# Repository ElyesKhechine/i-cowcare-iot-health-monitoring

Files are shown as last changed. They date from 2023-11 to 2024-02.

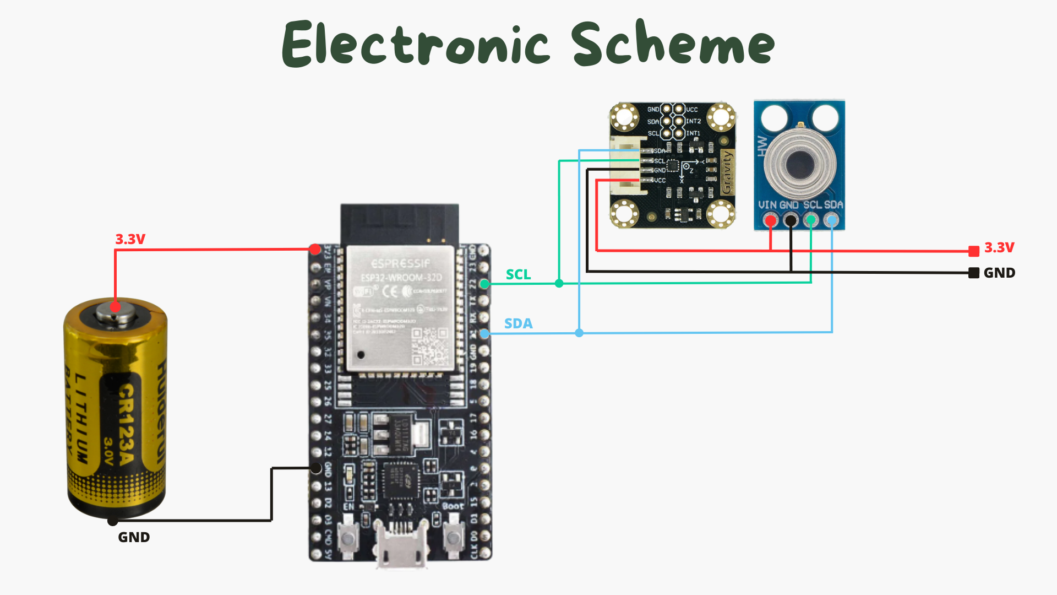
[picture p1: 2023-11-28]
Work_Progression/3_Meeting_10-04-2023/10-04-2023_Electronic_Scheme_I-CowCare_PFA_2022-2023.png

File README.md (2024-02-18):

# I-Cow-Care: IoT System for AI-Based Cow Health Monitoring

### INSAT IIA4

**Technologies:** Embedded C, ESP32, UART, I2C, MQTT, Mosquitto, CSV, JSON, Node-RED, Firebase, Edge Impulse, DNN

## Introduction

This project presents an IoT solution for cow health monitoring. The IoT device (Wearable Collar for cows) will help cow breeders detect cow health problems, and cow reproduction cycle in order to increase milk productivity and help prevent sickness and diseases among cows. This also gives the user easy access to the cow's vital indicators and helps predict its needs.

We used an ESP32, MLX90614 temperature sensor, LIS2DH accelerometer, and Lithium Polymer battery for power.

The steps below presenting the work done to establish the IoT network and prepare the hardware and software environment are going to be tackled with more details later.

1/ Install MQTT: MQTT will be our data transfer protocol using Wifi. We can use local or online MQTT servers. In our case we use Mosquitto MQTT locally and HiveMQTT as an online server.

2/ Prepare the script to connect to Wifi and MQTT, read data from sensors, and send data to the database/dashboard using MQTT protocol...(includes testing sensors, importing libraries, timestamp, etc.)

3/ Prepare the database for data storage and management using Firebase.

4/ Prepare a dashboard for data visualization and analysis using Node-RED.

5/ Hardware design: 3D mechanical and electronic design.

6/ Train machine learning models using Edge Impulse Platform for Embedded ML.

## Project Scope

Commencing from March 23, 2023, to June 1, 2023, the project undertook comprehensive research and development phases to design and implement an intelligent system for continuous cow health monitoring.

## Project Presentation

For a detailed overview of the project, including methodologies, findings, and outcomes, please refer to the [Project Presentation](https://www.canva.com/design/DAF2yuFe7VU/87OEpLmWulKL93VecQ9gpw/view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).

## Project Report

For comprehensive insights into project development, methodologies, and results, please refer to the [Project Report](https://drive.google.com/file/d/1peptsb_B581SGEHA1yHLA451OdRUzvFM/view?usp=sharing).

## Technical Details

- **Sensor Selection**: Careful selection of accelerometer and temperature sensors to optimize accuracy and efficiency, enabling over 3400 hours of continuous health monitoring with a 1300mAh lithium battery.
- **Custom Embedded C Library**: Development of a resource-efficient embedded C library for ESP32, facilitating seamless Wi-Fi connectivity, sensor data acquisition, and database publishing via MQTT, resulting in a 45% reduction in power consumption and memory utilization.
- **Data Acquisition and Storage**: Implementation of a streamlined process for data acquisition, storage, and retrieval, ensuring efficient communication with Firebase, transmission at 10 Hz, and generation of structured CSV files for DNN model training.
- **Node-RED Dashboard**: Creation of a Node-RED dashboard for visualizing body temperature and acceleration data, enhancing monitoring capabilities.
- **Supervised ML Models**: Collaboration on building supervised ML models using Edge Impulse, achieving a commendable 77% accuracy rate in classifying cow behaviors.

## Getting Started

# 1/ Installation and environment preparation

### Install Mosquitto MQTT 

in our case, the implementation was on Windows 10, and the procedure is similar for Linux, and MacOS

1/ Download link: https://mosquitto.org/download/
2/ Modify the configuration file:
To ensure the proper functioning of the Mosquitto broker, you need to manually modify the listener configuration for port 1883 in the configuration file in Mosquitto root folder.
3/ Start the MQTT server by running this command in the mosquitto root folder :
  
```bash
mosquitto -c mosquitto. conf -v
```
4/ To get the IP address, run this command (IPV4 in our case) :
```bash
ip config
```
5/ Configure the ESP32 code to connect to the MQTT server.

### Install Node-RED

1/ Download link: https://nodered.org/docs/getting-started/. You need to install node.js.

2/ Run Node-RED using this command :
  
```bash
node-red
```
3/ A local webpage will open in your browser to create, modify and connect your devices and different functions. You can connect to the database / MQTT server...

### Write script for ESP32 :

1/ We used Arduino IDE to program the ESP32  You'll find the whole script and library in the repository.

### Deep Learning :

1/ Data Preprocessing:  We engaged in data preprocessing, a step that involved tasks such as data cleansing, noise reduction, and handling missing values within the CSV dataset.

2/ Feature Extraction: We extracted spectral and temporal features from the preprocessed data.

3/ Neural Network Construction and Training: We designed and trained a neural network tailored to our dataset using the Edge Impulse platform. We then exported the TfLite model. 

Edge impulse link: https://edgeimpulse.com/

### 3D Design :
We used SolidWorks to design different parts of the device.

## Next Steps :
The project is far from being perfect or completed. The following steps may include enlarging and building a bigger database to ensure our sufficiency of data for model training. It may also include building a mobile application to facilitate access to data and different stats for different categories of users.

## Demo

### MQTT

MQTT1
MQTT2
MQTT3

### Firebase

Firebase realtime data

### Node-RED / Dashboard

begin cmd
dashboard nodes
dashboard1
dashboard2
dashboard3
### Edge Impulse

validation set


### Mechanical Design

CollarRender5
CollarRender4
CollarRender3
CollarRender2
CollarRender1
CollarNeck4
CollarNeck3

### Electronic Scheme

SCL

### Flow Diagram

SCL (1)

## Authors

This contribution to the project wasn't possible without the participation of the outstanding team :
- Edris Hadj Khlil: edris.hadjkhlil@insat.ucar.tn
- Majd Karoui: majd.karoui@insat.ucar.tn
- Niam Oueslaiti: niam.oueslaiti@insat.ucar.tn
- Elyes Khechine: elyes.khechine@insat.ucar.tn
  
And the supervision of our professors :
- Imen Harbaoui: imen.harbaoui@insat.ucar.tn
- Rabaa Youssef: rabaa.youssef@insat.ucar.tn

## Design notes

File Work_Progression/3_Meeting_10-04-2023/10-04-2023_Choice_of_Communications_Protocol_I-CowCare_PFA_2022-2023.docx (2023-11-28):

For cow heat detection devices on farms, MQTT or CoAP could be suitable protocols, as they are designed for low-bandwidth networks and can handle small data packets efficiently. Both protocols are also suitable for resource-constrained devices, which is important if the cow heat detection devices are small and battery-powered.

Additionally, the publish-subscribe model of MQTT could be beneficial for farms with multiple cow heat detection devices, as it allows for efficient communication between devices and a central server or cloud-based platform. CoAP's request-response model may also be appropriate for this type of application, as it allows for efficient exchange of information between the cow heat detection devices and the server.

The frequency of reading a temperature in the MLX90614 temperature sensor depends on how it is programmed and configured. The sensor can operate in two modes: continuous and single-shot.

In single-shot mode, the sensor provides a single temperature reading when it receives a trigger command from the device that is connected to it. The frequency of temperature readings in this mode depends on how often the trigger command is sent to the sensor.

the readout rate of the sensor can also vary depending on factors such as the communication protocol (I2C or SMBus), both of which have their own maximum transfer rates.

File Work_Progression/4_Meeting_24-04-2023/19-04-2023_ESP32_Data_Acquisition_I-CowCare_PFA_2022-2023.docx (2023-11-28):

- ESP32 Stockage : 520 KB of on-chip SRAM for data and instructions.
- 8 KB of SRAM in RTC, which is called RTC FAST Memory and can be used for data storage; it is accessed by the main CPU during RTC Boot from the Deep-sleep mode.
- 8 KB of SRAM in RTC, which is called RTC SLOW Memory and can be accessed by the co-processor during the Deep-sleep mode.

Temperature values :

1 feedback= 1 float = 4B

Accelerometer/Gyroscope values :

1 feedback = 6 floats = 24B

- code size : 206KB (memoire flash)

data storage and batch sending: aquisition frequency 4Hz

chaque 10s :

- temps de lecture : 0.4 s
- sleep mode 9.6

10s = 40 valeurs = 1KB

débit transmission de données via wifi : 19MB/s

à transmettre : 1KB

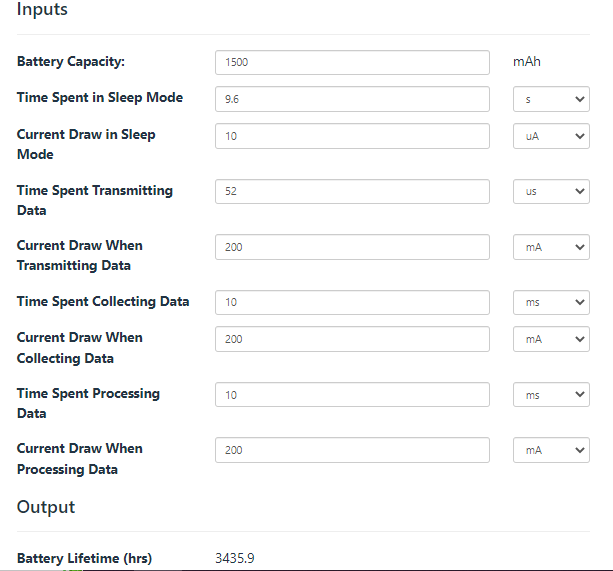
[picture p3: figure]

= 143 jours

Data cleaning au niveau du collier :

ESP32 is equipped with a dual-core processor that can run up to 240 MHz, which makes it capable of handling complex data processing tasks.

The suitability of ESP32 for data cleaning will depend on the specific requirements of the use case. Our data cleaning needs are rather simple , so the ESP32 can handle the tasks.

The data cleaning process takes time and consumes energy which reduces the collar’s battery life.

It's worth noting that the actual data cleaning process would typically occur on the server-side rather than on the collar itself, as the server typically has more processing power and storage capacity. The role of the collar would be to collect and transmit the raw data to the server for processing and analysis.

____________

Battery Life = Battery Capacity / [(Current Consumption of Controller + Current Consumption of Temperature Sensor + Current Consumption of Accelerometer) x Duty Cycle + Self-Discharge Current]

Duty Cycle = The percentage of time the device spends in active mode during a given period

Self-Discharge Current = The amount of current consumed by the battery during sleep mode. It can be estimated by considering the specifications of the battery and the quiescent current of the ESP32 board during sleep mode.

Example

To calculate the consumption of the controller, we can use the following formula:

Controller Consumption = 300 mA (during active mode) x Duty Cycle + Quiescent Current (during sleep mode)

Assuming a quiescent current of 20 uA during sleep mode, and a duty cycle of 1.11%, the controller consumption can be calculated as follows:

Controller Consumption = 300 mA x 1.11% + 20 uA

Controller Consumption = 3.33 mA + 20 uA

Controller Consumption = 3.35 mA

To calculate the current consumption of the temperature sensor, we can use the formula:

Temperature Sensor Consumption = 1 mA x Duty Cycle

Assuming a duty cycle of 1.11%, the current consumption of the temperature sensor can be calculated as follows:

Temperature Sensor Consumption = 1 mA x 1.11%

Temperature Sensor Consumption = 0.0111 mA

To calculate the current consumption of the accelerometer, we can use the formula:

Accelerometer Consumption = 200 uA x Duty Cycle

Assuming a duty cycle of 1.11%, the current consumption of the accelerometer can be calculated as follows:

Accelerometer Consumption = 200 uA x 1.11%

Accelerometer Consumption = 2.22 uA

The self-discharge current can be estimated based on the battery specifications and the quiescent current of the controller during sleep mode. Assuming a quiescent current of 20 uA during sleep mode, and a battery capacity of 1600 mAh, the self-discharge current can be calculated as follows:

Self-Discharge Current = Battery Capacity / (365 x 24 x 3600) x Quiescent Current

Self-Discharge Current = 1600 mAh / (365 x 24 x 3600) x 20 uA

Self-Discharge Current = 0.00000000221 A or 2.21 nA

Finally, we can calculate the duty cycle using the following formula:

Duty Cycle = Active Time / (Active Time + Sleep Time)

Assuming the system is active for 10 seconds every 15 minutes, the duty cycle can be calculated as follows:

Active Time = 10 seconds

Sleep Time = 15 minutes - 10 seconds = 899 seconds

Duty Cycle = 10 / (10 + 899) x 100

Duty Cycle = 1.11%

Using the values calculated above, we can estimate the expected battery life as follows:

Battery Life = Battery Capacity / [(Controller Consumption + Temperature Sensor Consumption + Accelerometer Consumption) x Duty Cycle + Self-Discharge Current]

Battery Life = 1600 mAh / [(3.35 mA + 0.0111 mA + 2.22 uA) x 1.11% + 2.21 nA] = 109.72 days

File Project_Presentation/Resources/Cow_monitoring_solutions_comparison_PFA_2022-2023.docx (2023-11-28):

Afimilk:

Utilizing a unique 3D accelerometer, Afimilk enables efficient monitoring of motion patterns. The Afi2Go Pro mobile app provides convenient access to the system from anywhere, at any time. With its robust mechanical design, Afimilk achieves a remarkable 95% detection sensitivity in various farm conditions. By employing three sensors, Afimilk enhances detection capabilities. The electrical design of Afimilk ensures an extended battery life spanning multiple years. Afimilk boasts a range of 200-800m. Currently, Afimilk's technology manages over 10 million cows in 52 countries worldwide.

__________________

Nedap:

Nedap offers a neck and leg tag system for dairy cows. The system includes features such as heat detection, cow locating, and health monitoring. It provides herd performance trends and delivers real-time information on all devices for multiple users, including PCs, tablets, and smartphones. The data is transferred wirelessly in real-time with a sensitivity of 95% and specificity of 95%. The tags have an expected service life of 8-10 years. They also support long-range data transfer and are constructed using robust materials engineered to withstand the farm environment.

__________________

Smartbow

INDUSTRY-LEADING RUMINATION MONITORING: provides the most accurate rumination monitoring in the industry, 97% to 99% accuracy delivers two types of rumination alerts — an urgent decline in rumination and a long-term decline in rumination.

UNPARALLELED HEAT DETECTION: heats can be detected with a reliability of 97% generates alarms on smartphones, tablets and desktop computers

Price: 2.500$ for the installation +69$ per cow (only for heat detection)

__________________

Smaxtec Cowcontrol

SMAXTEC BOLUSES CONTINUOUSLY COLLECT DATA: The rumen bolus measures direct, insightful values with the highest accuracy inside your cows, in the reticulum. The bolus remains inside the cow for a lifetime. It remains in the same position due to its own weight, and is neither regurgitated nor digested.

HEAT DETECTION allowing higher inseminaiton success

24/7 MONITORING

EARLY DETECTION

optimized for PC and phone (IOS,ANDROID)

RECOMMENDED ACTIONS using AI

ensuring herd health

calving detection

Price: 89$ +2.49$ per cow per month(data interpretation)

__________________

The MooMonitor+ is a state-of-the-art system that utilizes cloud computing, wearable sensors, and big data to enhance health and reproductive monitoring for cows. It enables easy detection of heats by monitoring the entire herd through the phone application, MooMonitor+. Real-time notifications provide updates on the cows' activity and health. The pricing for the system includes €140 per collar, €4,500 for the base station, and an additional charge of €5 per cow per year for the cloud monitoring system.

_________________

Moonyst Catle Monitoring

Plug & Play installation, optimized for phone, tablet and PC

Real-time access via cloud computing with 24/7 rumen monitoring

Boluses are maintenance-free, orally administered sensors with unique IDs and 6+ years battery life

Captures animal activity, rumen temperature, and movement

Mooncloud software application provides dedicated location for livestock information accessible via phone, tablet or PC

Supports calving, facilitates insemination, and prevents diseases

Improves success rates with insemination and provides real-time alerts of calving events (days/hours in advance)

Enables timely and targeted medication treatments with advanced warning of health concerns

Precise monitoring of drinking behavior for feeds into animal health monitoring

Artificial intelligence used for individual animal heats identification and prediction

Enhances expert herdsmanship with technology

Tailored status periods within Mooncloud for each cow's specific status.

size: 100 mm × 32 mm // weight: cca. 200g

__________________

e-Stado:

Sensors:

-Ear biosensors

-Environment sensor

-Tail biosensor

-Radio transmitters in the cowshed and pasture

-Cowshed monitor

Features:

Health:

-Measurement of inactivity to identify potential threats

-Measurement of ear temperature to detect health issues

Reproduction:

-Detection of heat for optimal timing of insemination

-Estimation of the optimal insemination window

Calving:

-Estimation of the incoming calving time

-Postpartum retention monitoring

Feeding:

-Monitoring of rumination time

-Monitoring of feed intake time

Photoperiod:

-Measurement of individual photoperiod cycles

Heat stress:

-Detection of individual heat stress

-Measurement of barn humidity

-Measurement of barn temperature

-Calculation of barn THI (Temperature-Humidity Index) Lameness:

-Early detection of lameness stages.

__________________

CowManager

Real-time monitoring of cow behavior and health using wireless router located in the farm

Wireless ear tags with long-lasting batteries

Cloud-based software with a user-friendly interface

Customizable alerts

Integration with other farm management systems

Sustainability-focused approach.

Real time Monitoring

Detects fertility, illness, activity, eating behaviour

__________________

Ayushman Cowfit

Uses IoT technology to monitor cattle health

Early detection of health issues

Collar with sensors on the cow's neck

Cloud-based analysis with real-time insights and alerts

User-friendly mobile app and web portal

Actionable recommendations for improving cattle health

Cost-effective and scalable

Reduces need for frequent check-ups and saves time and money.

Price: €90 per collar

__________________

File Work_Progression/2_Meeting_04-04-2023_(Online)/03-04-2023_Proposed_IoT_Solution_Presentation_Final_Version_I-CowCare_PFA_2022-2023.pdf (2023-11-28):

# ICowCare

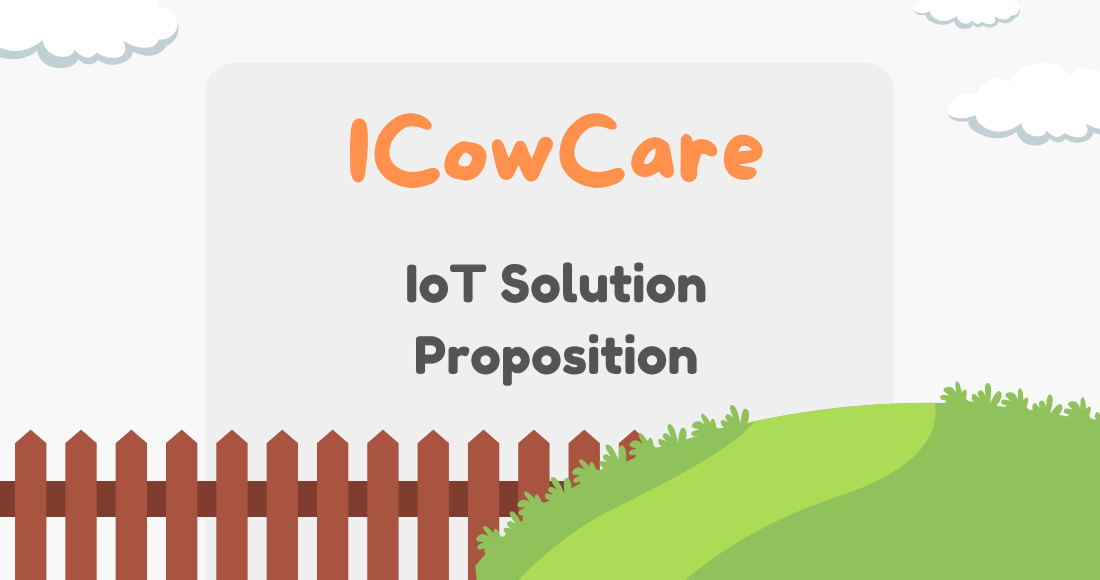
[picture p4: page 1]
IoT Solution Proposition

# Development board

## ESP32-DevKitC V4

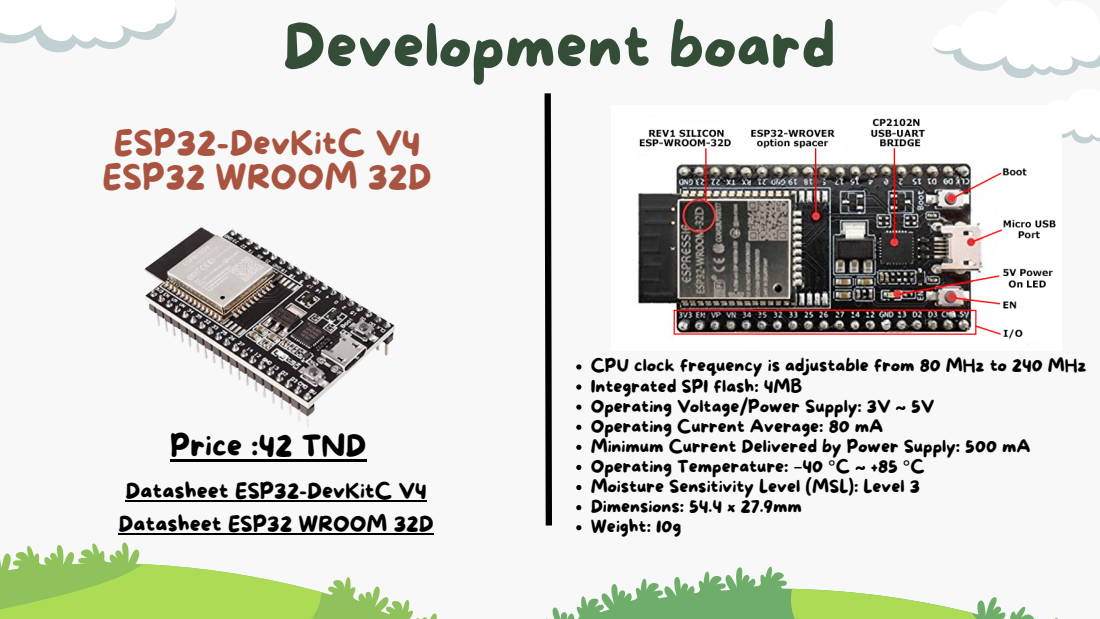
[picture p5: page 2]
ESP32 WROOM 32D; Price :42 TND; Datasheet ESP32-DevKitC V4 Datasheet ESP32 WROOM 32D

CPU clock frequency is adjustable from 80 MHz to 240 MHz
Integrated SPI flash: 4MB
Operating Voltage/Power Supply: 3V ~ 5V
Operating Current Average: 80 mA
Minimum Current Delivered by Power Supply: 500 mA
Operating Temperature: –40 °C ~ +85 °C
Moisture Sensitivity Level (MSL): Level 3
Dimensions: 54.4 x 27.9mm
Weight: 10g

# Power Supply

## Lithium battery CR123/CR123A

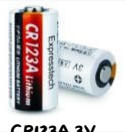
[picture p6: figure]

CR123A 3V
1300MAH
Price :9.5TND
Seli.tn (https://seli.tn/page1?recherche=cr123)

These keep a voltage of 3V quite constant, at less than 2.7 volts more than 90% of the capacity of a lithium battery is used, at 2.55 volts it is practically empty. Lithium batteries also provide the high short-term power requirements of WiFi operation without any problems. For example, a Varta CR123 (3V, 1700 mAh) can even be used in standby mode for over 5 years, depending, of course, on how often the ESP32 wakes up and has to do something, or how long and how often WiFi or Bluetooth is used.
As lithium batteries have a very low self-discharge and also function well at -20 °C,

ANSMANN 3V
1500MAH
Price :15.5TND
brico-direct.tn (https://brico-direct.tn/piles-batteries/2366-pile-speciale-cr123a-ansmann-4013674020010.html)

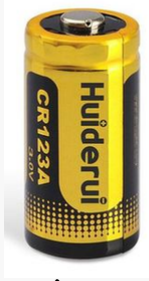
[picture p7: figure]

Huiderui 3V
1600MAH
Price :17TND
jumia.tn (https://www.jumia.com.tn/huiderui-pile-3v-batterie-au-lithium-primaire-cr123a-688849.html)

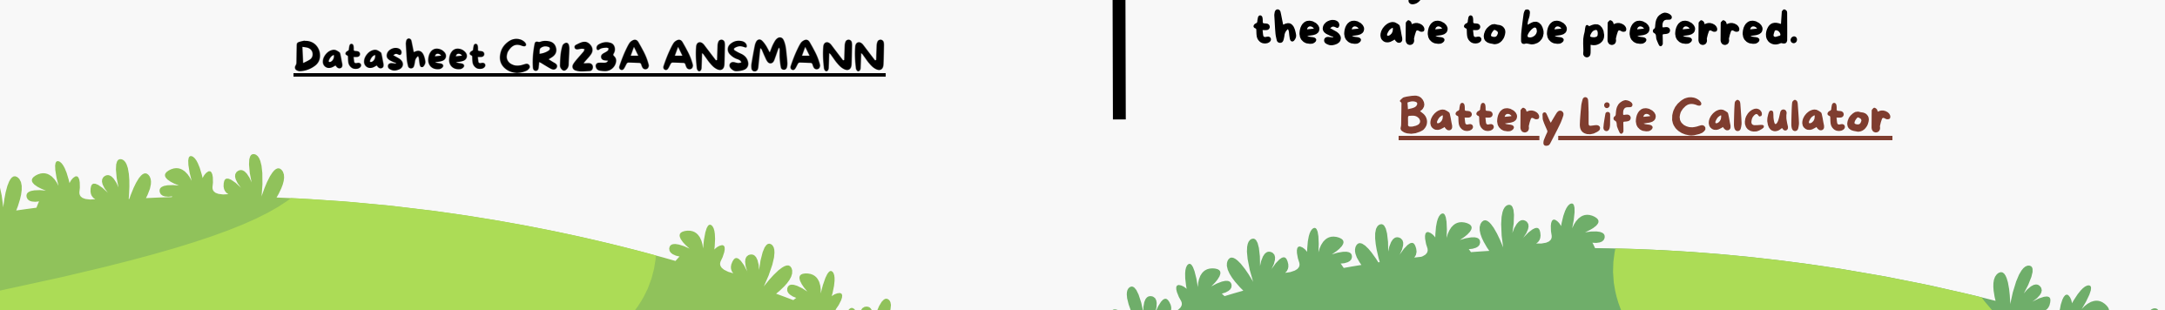
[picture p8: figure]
Datasheet CR123A ANSMANN; these are to be preferred.; Battery Life Calculator

# Server

### SERVEUR RACK DELL

POWEREDGE R230 (https://www.tunisianet.com.tn/serveur-informatique-tunisie/49088-serveur-rack-dell-poweredge-r230-2-to-8-go.html)

Reliability: The Dell PowerEdge R230 is a reliable server that is built to withstand long hours of operation.
Performance: The server is powered by an Intel Xeon E3-1220 v6 processor, which offers good performance for tasks such as cow monitoring.
Storage: The server comes with 2TB of storage, which should be enough
RAM: The server has 8GB of RAM, which is adequate for running the applications required.
Connectivity: The server has built-in Ethernet connectivity, which makes it easy to connect to the network and access the

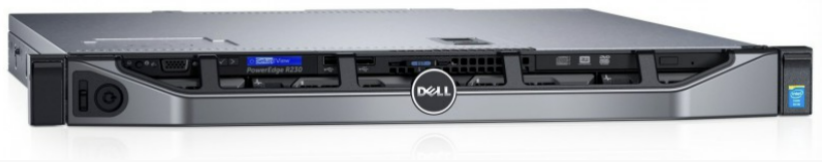
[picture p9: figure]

Price: 2.739

mytek (https://www.mytek.tn/serveur-dell-poweredge-r230-e3-1220v6-8go-1to-1u-per230a1.html) 2.549

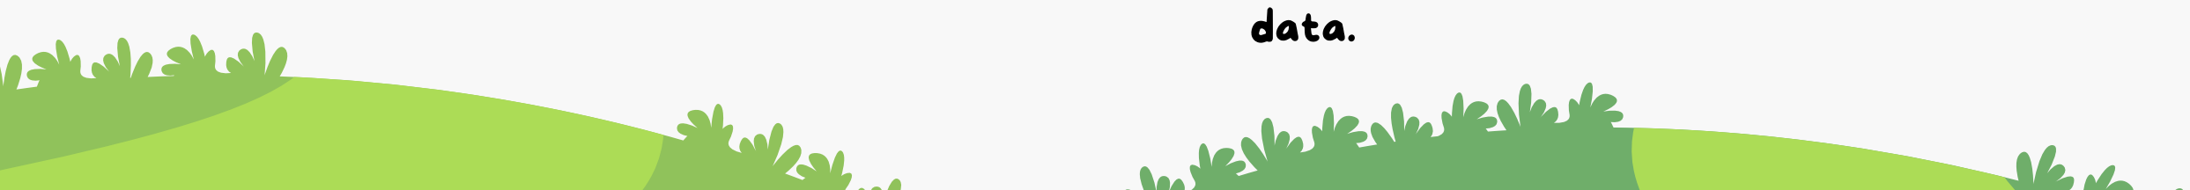
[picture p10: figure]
data.

# Cloud option

Requires good internet connection can incur ongoing costs, such as data transfer and storage fees.

AWS (https://aws.amazon.com/pricing/)
Azure (https://azure.microsoft.com/en-us/pricing/)
Google Cloud Platform (https://cloud.google.com/pricing)

Here are the links to the pricing pages for each
AWS | provider:

: starts at around $10 per month for a basic t2.micro instance with 1 vCPU and 1GB
RAM.
Azure: starts at around $15 per month for a basic B1s instance with 1 vCPU and 1GB RAM.
Google Cloud Platform: starts at around $10 per month for a basic f1-micro instance with 1 vCPU and 0.6GB RAM.

the pricing for AWS, Azure, and Google Cloud Platform can vary widely depending on factors such as the specific services used, the location, and the duration of usage. However, here are some rough estimates for the cost of running a basic virtual machine in each cloud provider:

# Arduino Cloud

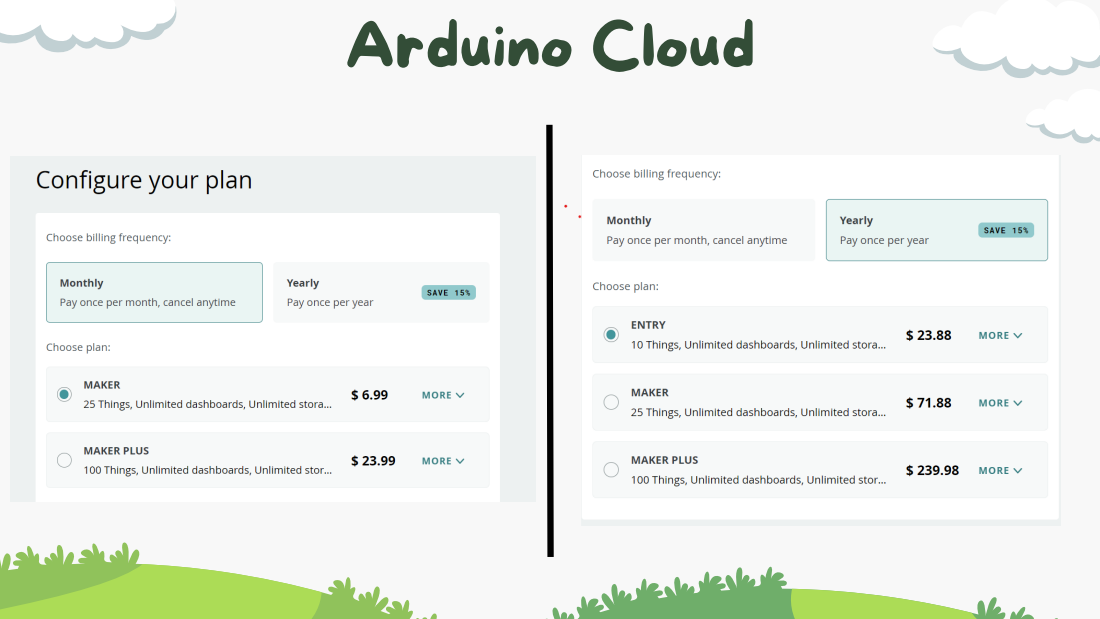
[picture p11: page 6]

### Sensors Temperature sensor

GY-906 MLX90614

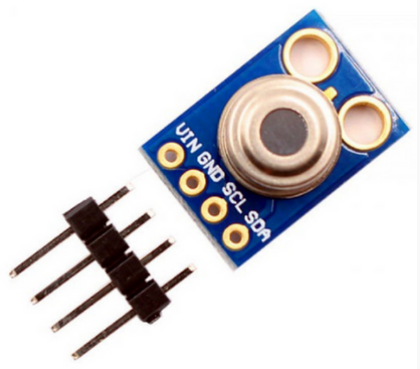
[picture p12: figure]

The GY-906 MLX90614 is a high precision infrared non-contact thermometer module with I2C interface and 5V or 3.3V operation.
Due to its high accuracy and precision, it is also used in a wide range of commercial and

Non-contact measurement: perfect for measuring the temperature of moving objects. Temperature measurement range: -70°C to +380°C
I2C/SMBus interface
Optional PWM and interrupt output
The module has a 3.3V regulator on it. It can

The main difference between this and most other thermometers is that the temperature reading is taken without contacting the object whose temperature is being monitored
key features:

3.3V or 5V operation

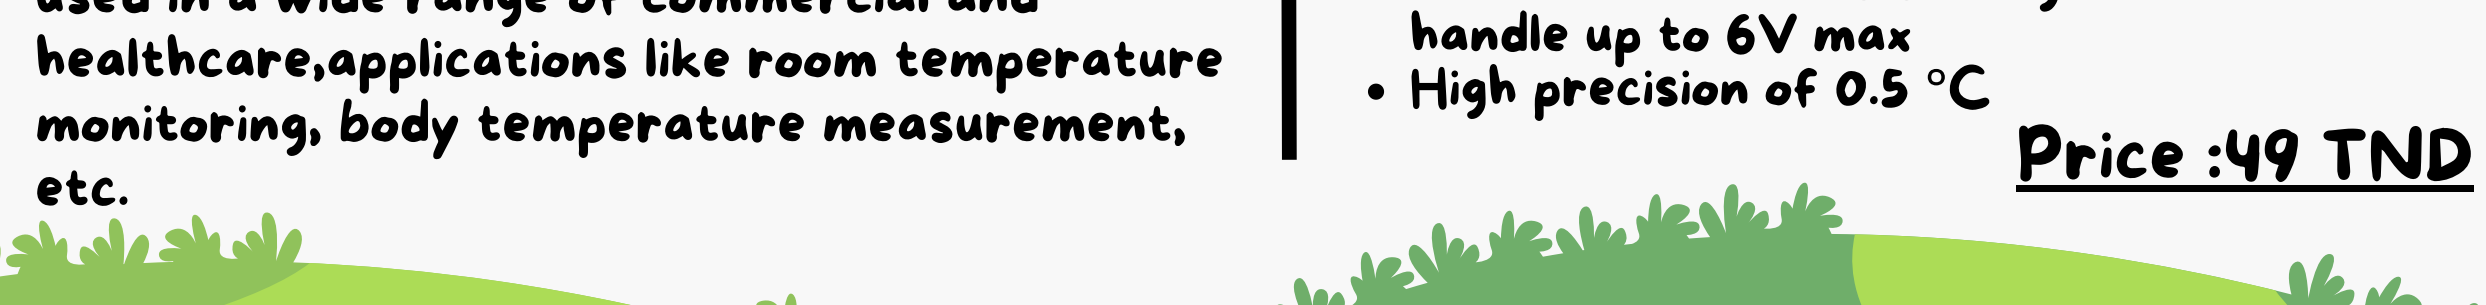
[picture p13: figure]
healthcare,applications like room temperature monitoring, body temperature measurement, etc.; handle up to 6V max High precision of 0.5 °C; Price :49 TND

### Sensors Accelerometer sensor

Gravity LIS2DH
The LIS3DH is a similar, but more expensive option with the added capability of providing 16-bit output, providing more accurate data.
The choice between the two sensors will depends on the specific needs and requirements of the cow monitoring IoT solution, the budget, and the

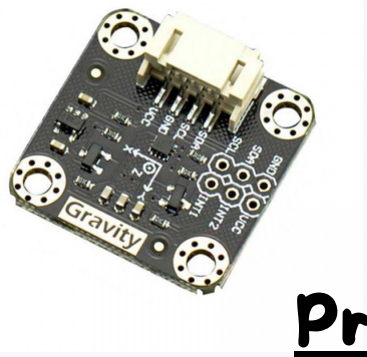
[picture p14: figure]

Price : (https://2betrading.com/cartes-de-developpement/1484-gravity-i2c-triple-axis-accelerometer-lis2dh.html)20.5 TND (https://2betrading.com/cartes-de-developpement/1484-gravity-i2c-triple-axis-accelerometer-lis2dh.html) availability of the products.

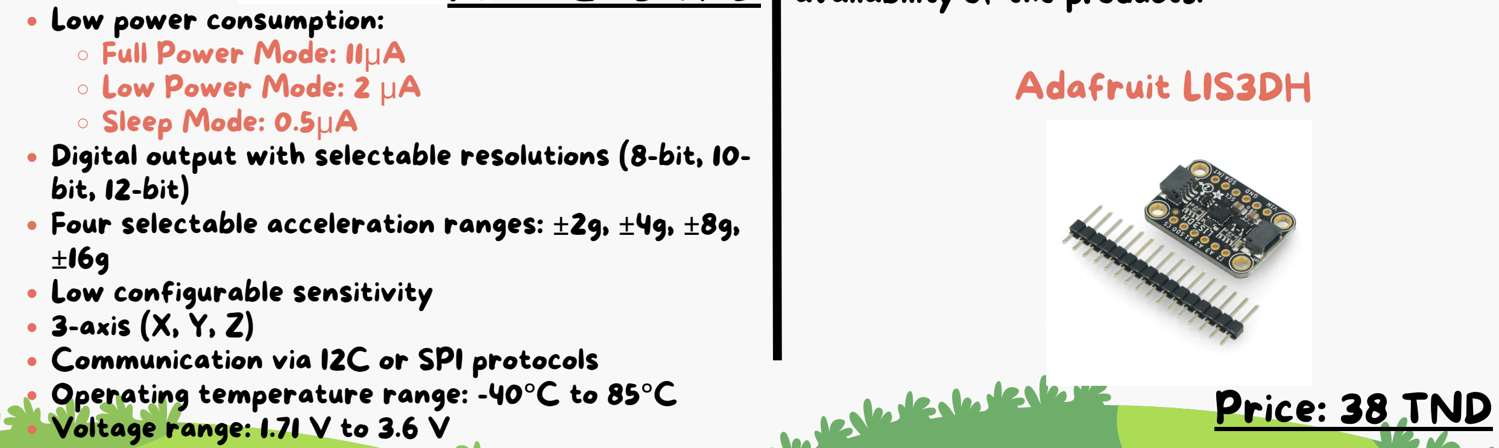
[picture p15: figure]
Low power consumption: Full Power Mode: 11µA Low Power Mode: 2 μA Sleep Mode: 0.5µA; bit, 12-bit); ±16g Low configurable sensitivity 3-axis (X, Y, Z) Communication via I2C or SPI protocols; Voltage range: 1.71 V to 3.6 V; Adafruit LIS3DH; Price: 38 TND

Digital output with selectable resolutions (8-bit, 10-

Four selectable acceleration ranges: ±2g, ±4g, ±8g,

Operating temperature range: -40°C to 85°C

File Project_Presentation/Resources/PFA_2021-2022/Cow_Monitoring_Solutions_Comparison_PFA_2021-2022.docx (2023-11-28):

Outil | Intérêt | Limite | Coût
Vel’phone (vêlage) | -Monitoring continu -Bonnes sensibilité (98%) et spécificité (100%) dans les dernières heures précédant le vêlage -Facilité de mise en place | -Faibles sensibilité et spécificité de prédiction au-delà des 4 dernières heures -Invasif -Risque d’infection si l’antiseptie est insuffisante -Perte du thermomètre fréquent au moment de son éjection (surcoût élevé) | 3500€ (kit + 3 à 5 thermomètres vaginaux), sans base radio, ni abonnement
Smart’vel (vêlage) | -Monitoring continu -Facilité de la pose - Non invasif | Pas d’études sur la spécificité et la sensibilité | 3350€/ 5 capteurs
Alert’vel (vêlage) | -Monitoring continu -Facilité de la pose -Non invasif | Pas d’études sur la spécificité et la sensibilité | 3500€/ 2 capteurs
Ceinture Agrimonitor (vêlage) | -Monitoring continu -Non invasif | -Difficulté de mise en place | 3500€ (2 ceintures)
Moocall (détection de vêlage) | | Pas d’études sur la spécificité et la sensibilité | 299 € par vache
Capteur de rumination ART | | Pas d’études sur la spécificité et la sensibilité | 3750€/ 5 colliers
Cell-Detek | | | 507,00 €
Accéléromètre | | | 4,5 à 8 k€ (50 vaches)
Podomètre | Efficacité > 60% | Précision : 22-100% | 4,5 à 8 k€ (50 vaches)
Heatime HR (Chaleur) | Sensibilité : 77% VPP : 72-82% | | 9 000 – 10 000 € pour 50 vaches
Heatime (Chaleur) | Sensibilité : 62% VPP : 64-77% | | 5,3 k€ (20 colliers soit 50 vaches)
Glucomètre | | | 69 €
Bolus smaXtec (trouble métabolique) | | | £4,8 k pour 50 vaches
Butyromètre | | | 4-15 €
SMARTBOW ear-tag (chaleur) | Sensibilité : 96.6% Spécificité : 97.7% VPP : 95.8% | | 7,5 k £ (50 vaches)
Détecteur électronique de chevauchement (chaleur) | Taux de détection : 70-90% | Faible exactitude : 50% | 6,5 k€ (50 vaches)
Afilab (comptage cellulaire, calcul du taux protéique et butyreux, mesure du lactose, détection du sang dans le lait, conductivité du lait) | | | 4 500 € à 7 000 €

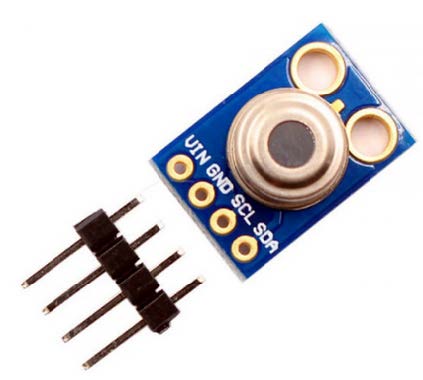
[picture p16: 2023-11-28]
Project_Presentation/Resources/Images/temperature_sensor_GY-906_MLX90614.jpg

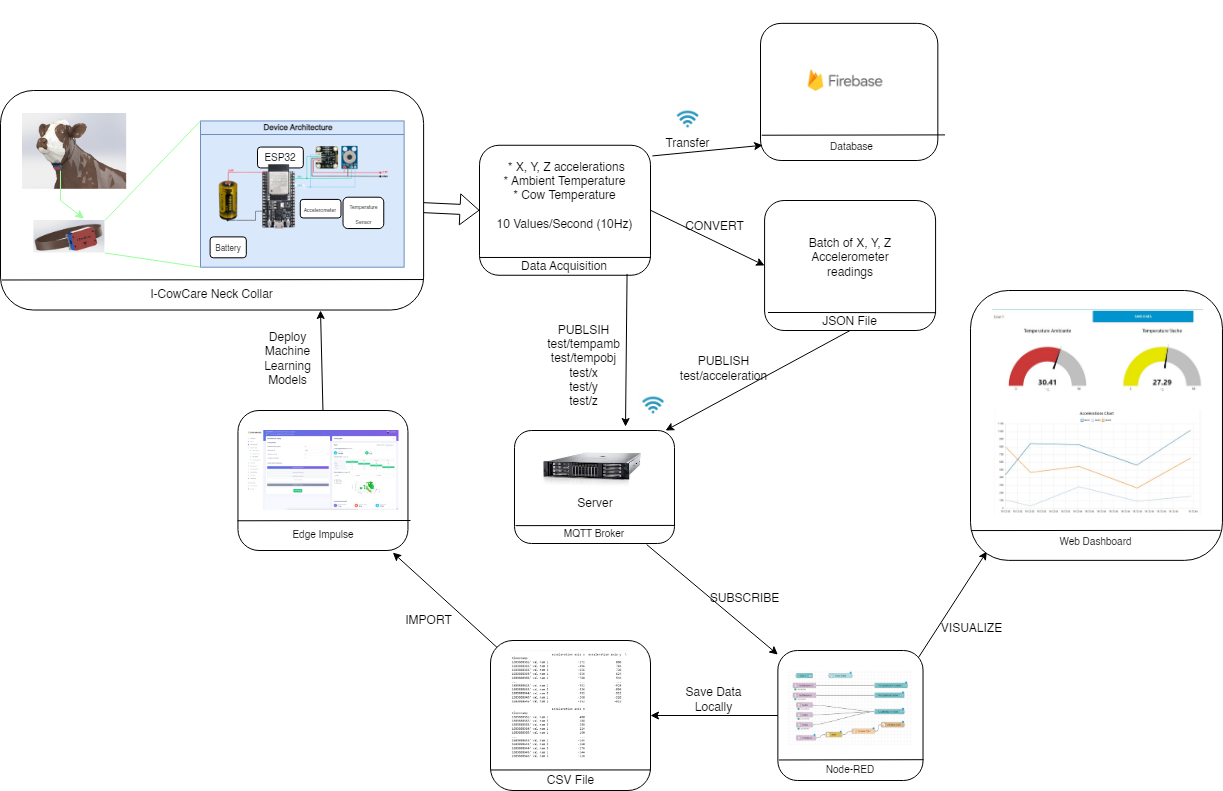
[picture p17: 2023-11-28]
Project_Presentation/Resources/Images/use_case_flow_diagram.png

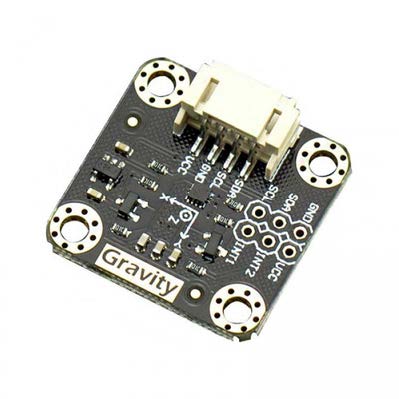
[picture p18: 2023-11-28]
Project_Presentation/Resources/Images/accelerometer_sensor_LIS2DH.jpg

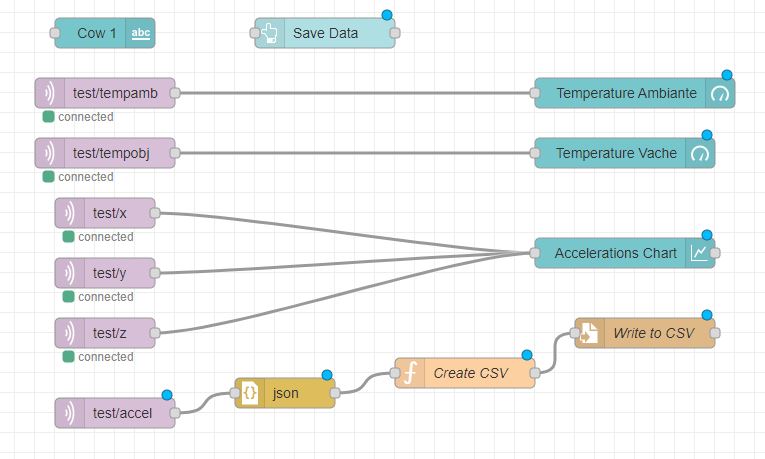
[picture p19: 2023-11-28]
Project_Presentation/Resources/Images/node-red_diagram.jpg

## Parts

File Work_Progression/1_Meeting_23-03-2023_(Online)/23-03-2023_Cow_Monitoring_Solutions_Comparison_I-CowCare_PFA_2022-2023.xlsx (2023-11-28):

Product Name | Price | Sensors | Data Collection | Analytics | User Interface | Accuracy | Scalability | Technologies Used | Maintenance | Link
Ayushman Cowfit | 90 Euro | Rumination (%), Body Temperature, Standing/Sitting, Activity level, Heat Cycle, Lameness and GPS Location of the cattle | timely alerts | AI based analytics models with custom algorithms. | mobile app and web browser |  |  |  |  | Ayushman Cowfit - Areete (https://www.areete.org/products-and-solutions/ayushman-cowfit/)
Nedap CowControl | - | Temperature, rumination, activity, eating and drinking | Real-time, wireless | Machine learning | Mobile app, web portal/PC, tablet and smartphone | 95% sensitivity, 95% specificity | Up to 10,000 cows | IoT, cloud computing, data analytics | Maintenance contract required | https://www.nedap-livestockmanagement.com/dairy-farming/solutions/nedap-cowcontrol/health-monitoring/
Aficollar | - | Temperature, rumination, activity, eating and drinking | Real-time, wireless | Machine learning | mobile app/PC-based programme |  |  | iot, machine learning,cloud computing | no maintenance needed | https://www.afimilk.com/cow-monitoring/#afi-collar | https://www.afimilk.com/the-benefits-of-the-afimilk-heat-detection-system/
smartxtec | $89 with a monthly data interpretation fee of $2.49 per cow/£9,800 for a 100-cow | heat detection,herd health,calving detection | real time,wireless |  | mobile app /pc |  |  | SMAXTEC TRUD™ , using bolus in the reticulum | no maintenance neaded | https://smaxtec.com/en/
cowmanager |  | heat detection via ear sensor;detects fertility,detect illness,activity,eating behaviour | real_time,using wirelless router located in the farm |  |  |  |  | data analytics,iot |  | https://www.cowmanager.com/cow-management/system/
moomonitor | 4,500$ for the base+140$ per collar+5$/cow/year for cloud monitoring | Temperature, rumination, activity, eating and drinking |  |  |  |  |  |  |  | https://www.dairymaster.com/fr/products/moomonitor/
beco
Lely Qwes-H system | c$ 155.02 | The system uses collar-mounted cow identification and activity sensors, which measure movement duration and intensity using a sophisticated acceleration sensor. The Lely Qwes-HR also includes a rumination microphone. | The system monitors cows' activity in two-hour time blocks and records a general activity index. It also analyzes vocal signals to calculate rumination time. | The system provides highly accurate, high-resolution views of individual cow behavior, allowing for optimized reproduction, minimized calving intervals, and reduced semen costs. It can also detect changes in rumination, an early indication of potential health problems | The system is managed through the Lely T4C management program, which includes a dynamic feeding module and dynamic milking features. The Benchmark within T4C allows farmers to compare their results with those of other farmers around the world. | the system provides highly accurate and detailed information on individual cow behavior, allowing for optimized reproduction and early detection of potential health problems. |  | The system uses collar-mounted cow identification and activity sensors, acceleration sensors, rumination microphones, microprocessors, and memory. |  | https://www.lely.com/media/filer_public/4c/35/4c356264-6d60-41c8-864d-d59ac248bed7/lely_dairy_equipment_-_english.pdf
Weizur Neck Cow Monitoring System | - | Neck-mounted sensor | Real-time monitoring | Machine learning-based | Mobile app, web dashboard | High, up to 99% | High, can handle large herds | LoRa, Bluetooth, cloud computing | Regular check-ups required | https://www.weizur.com/en/producto/neck-cow-monitoring-system/
Jenysis Portable Heat Detection
Smartbow | £69 per cow for heat detection only | Temperature, rumination,
SenseHub™ Dairy | N/A | The system offers a choice of neck or ear tags for cow identification and monitoring of reproductive, health, nutritional, and wellbeing status. The system claims to offer unmatched heat detection accuracy and precise insemination timing guidance. | SenseHub provides actionable information on individual cow and group behavior through advanced monitoring and data analytics. The system is designed to deliver proactive, individualized health management. | The system uses advanced data analytics to provide actionable insights for improving productivity, reproductive health, and wellbeing of individual cows and groups. | SenseHub offers multiple user device options, and the application plan is flexible, allowing dairy farmers to choose the level of functionality that suits their needs. | SenseHub claims to offer unmatched heat detection accuracy and precise insemination timing guidance, providing dairy farmers with the data they need to make informed decisions for maximizing productivity. | The system is modular and can be expanded or changed to fit evolving needs. It delivers long-term investment protection and can be easily upgraded. | SenseHub uses sophisticated sensor technology, advanced data analytics, and user-friendly interfaces to deliver actionable information on individual cow and group behavior. | The system is simple to install, use, and maintain, providing dairy farmers with a reliable and cost-effective solution for monitoring cow behavior and improving productivity. | https://www.allflex.global/ie/product/sensehub-solution-for-dairy-cows/
Moonyst Cattle Montoring | Smart Rumen Bolus // temp + activity // 99 € / device* Smart Rumen Bolus pH // temp + activity + pH // 349 € / device* Gateway // Including SIM Card with unlimited usage and power cable // 1,999 € Monthly rental available Mooncloud // Cloud based software // Free of Charge No Software or Hardware Maintenance Fees | The Smart Rumen Bolus is a sensor that is orally administered by a farmer or veterinarian, using a standard bolus gun. The bolus is designed to capture animal activity, rumen temperature, and movement. The bolus can be applied to animals of 350+ kgs. The bolus communicates with a Gateway, over a wide geographical area. Each bolus has a unique ID that can be associated with the animal. The material of the bolus is an acid-proof resin which protects the electronic parts and causes no harm inside the animal. The bolus is equipped with a battery that has a 6+ years life span. | The Moonsyst Monitoring System collects data from the animal via a communication Gateway, to dedicated cloud-based servers. Farmers can access their specific information anywhere, anytime via the Mooncloud software application. Mooncloud provides a dedicated location for livestock information. Mooncloud supports push notifications directly to the App and email, that helps improve the daily routine on the farm and work-life balance. The Mooncloud software will also alert the farmer of any changes to an animal’s rumen temperature or activity, such as changes in drinking habits. | The Smart Rumen Bolus captures animal activity, rumen temperature, and movement. Mooncloud software provides a simple graphical visualization of information, presenting actionable management decisions to farmers, vets, and feeding experts on the health, wellbeing, reproduction, and nutrition at animal and herd level. Mooncloud generates heat alerts and optimal windows for insemination. Mooncloud provides real-time alerts of calving events (days/hours in advance) and advanced warning of health concerns. Mooncloud supports timely and targeted medication treatments and less use of antibiotics. | Mooncloud can be accessed by phone, tablet, or PC anywhere, anytime. Mooncloud software provides a simple graphical visualization of information. Mooncloud software provides actionable management decisions to farmers, vets, and feeding experts. Mooncloud supports push notifications directly to the App and email, that helps improve the daily routine on the farm and work-life balance. | The Smart Rumen Bolus captures animal activity, rumen temperature, and movement. Mooncloud generates heat alerts and optimal windows for insemination. Mooncloud provides real-time alerts of calving events (days/hours in advance) and advanced warning of health concerns. Mooncloud supports timely and targeted medication treatments and less use of antibiotics. | The Smart Rumen Bolus can be applied to animals of 350+ kgs. The bolus communicates with a Gateway, over a wide geographical area. Farmers can access their specific information anywhere, anytime via the Mooncloud software application. Mooncloud provides a simple graphical visualization of information, presenting actionable management decisions to farmers, vets, and feeding experts on the health, wellbeing, reproduction, and nutrition at animal and herd level. | The Smart Rumen Bolus is made of an acid-proof resin which protects the electronic parts and causes no harm inside the animal. The bolus is equipped with a battery that has a 6+ years life span. The Moonsyst Monitoring System collects data from the animal via a communication Gateway, to dedicated cloud-based servers. Farmers can access their specific information anywhere, anytime via the Mooncloud software application. Mooncloud software provides a simple graphical visualization of information, presenting actionable management decisions to farmers, vets, and feeding experts on the health, wellbeing, reproduction, and nutrition at animal and herd level. | The Smart Rumen Bolus is maintenance-free and designed to be easily swallowed, staying in the rumen for up to 6 months without needing any intervention or maintenance. This means farmers can save time and effort in monitoring their cattle's health, reducing the need for frequent veterinarian visits and decreasing labor costs. The device is also resistant to rumen acid and can withstand the harsh conditions within the rumen, ensuring its longevity and durability. | https://moonsyst.com/bolus
e-stado |  | One of the key components of e-stado is its use of sensors. These sensors are designed to collect data on a wide range of environmental factors, such as temperature, humidity, and air quality. They are typically placed in strategic locations throughout a given area, and are capable of gathering data in real-time. The use of sensors is critical for providing accurate, up-to-date information on environmental conditions, which is essential for effective decision-making. | e-stado is designed to collect data from a variety of sources, including sensors, mobile devices, and other IoT devices. The data collected is then processed and analyzed to provide valuable insights that can be used to optimize various processes. With e-stado, data collection is fast, efficient, and reliable, which means that users can make decisions based on real-time data that is accurate and up-to-date. | e-stado provides powerful analytics capabilities that allow users to gain insights from the data collected. Using advanced algorithms and machine learning techniques, e-stado can identify patterns and trends in the data that would be difficult to identify manually. This enables users to make informed decisions based on data-driven insights and optimize their operations. | The user interface of e-stado is designed to be intuitive and easy to use. It provides a customizable dashboard that allows users to view the data collected in real-time and access analytics tools. The dashboard can be customized to suit the specific needs of each user, making it easy to access the information they need at a glance. | e-stado is designed to provide accurate and reliable data. By using a combination of sensors and other data collection methods, e-stado can provide real-time data that is accurate and up-to-date. This means that users can make informed decisions based on reliable data, which can lead to better outcomes and improved efficiency. | e-stado is highly scalable and can be customized to meet the needs of any organization. Whether you are a small business or a large corporation, e-stado can be customized to meet your specific requirements. This means that as your business grows and your needs change, e-stado can adapt to meet those changes. | e-stado is built using the latest technologies and is designed to be highly flexible and adaptable. It uses a combination of IoT devices, sensors, and other data collection methods to gather real-time data. This data is then processed and analyzed using advanced analytics tools and machine learning algorithms. The result is a powerful platform that provides valuable insights and helps businesses optimize their operations. | e-stado is designed to be easy to maintain and manage. It is a cloud-based platform that can be accessed from anywhere with an internet connection. This means that users can manage their operations and monitor their data in real-time from any location. Additionally, e-stado is designed to be highly secure, with regular updates and maintenance to ensure that it is always up-to-date and protected against threats. | https://e-stado.net/product-offer/

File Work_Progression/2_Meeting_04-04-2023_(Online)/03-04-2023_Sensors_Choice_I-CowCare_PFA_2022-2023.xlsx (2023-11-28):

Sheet: Ear-tag
Information about currently available ear-tag and halter type sensor.
Product | Company (Parent Company) | Country | Management Software | Mobile Application | Dimensions (mm × mm × mm) | Weight (g) | Battery Life | Range (m) | Built-in Sensors | Output Data | Data Reporting Frequency | Detection
Ear tag
Smartbow | Smartbow GmbH (Zoetis Services LLC.) | AT | Herd Monitoring Software | ○ | 52 × 36 × 17 | 34 | 2 years | 300 | Accelerometer Temperature sensor | High activity/Activity/Inactivity/Ruminating time/Location | Every hour | Heat/Health disorder
eSense Flex tag | SCR Engineers Ltd. (Allflex Europe SA) | IL | SenseHub™/ Heatime® Pro+ | ○ | 68 × 38 × 15 | 25 | 3 years | 200 × 500 * | Accelerometer | Activity/Ruminating time/Heat index | Every 2 h | Heat/Health disorder
CowManager SensOor | Agis Automatisering BV | NL | CowManager System | ○ | 60 × 50 × 22 | 32 | 5 years | - | Accelerometer Temperature sensor | High activity/Activity/Inactivity/Ruminating time/Eating time/Temperature/(Location) | Every hour | Heat/Health disorder
TekSensor tag | TekVet Technologies Co. | NL | TekAccess™ | × | - | - | - | - | Temperature sensor | Temperature | Every hour | Health disorder
Calf Tag | FeverTags LLC | US | TempVerified | × | - | 14 | 2 years | - | Temperature sensor | Temperature | Every 15 min | Health disorder
Data Collection Tag | FeverTags LLC | US | - | × | - | - | - | - | Temperature sensor | Temperature | Every 15 min | Research purpose (Data acquisition only)
Halter
RumiWatch Noseband Sensor | ITIN + HOCH GmbH | CH | RumiWatch Manager/RumiWatch Converter | × | - | - | 2 years | - | Accelerometer Temperature sensorPressure sensor | Raw activity/Other chewing activity/Ruminating time/Regurgitated boli counts/Ruminating chew counts/Chews per bolus/Chews per minute/Eating time/Eating chew counts/Drinking time/Drinking gulp count/Temperature (ambient) | Every minute /Every hour | Research purpose (Data acquisition only)
* Area coverage.

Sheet: Neck collar type sensor
Product | Company (Parent Company) | Country | Management Software | Mobile Application | Dimensions (mm × mm × mm) | Weight (g) | Battery Life | Range (m) | Built-In Sensors | Product (Module) | Output Data | Data Reporting Frequency | Detection
CowScout Neck | GEA Farm Technologies, Inc. | DE | CowScout Activity monitoring system | ○ | - | - | 5 years | 100–1000 | Accelerometer | CowScout Neck | Activity/Inactivity/Ruminating time/Eating time | Every 2 h | Heat/Health disorder
Rescounter III Neck | GEA Farm Technologies, Inc. | DE | DairyPlan C21 | × | - | - | - | - | Accelerometer | Rescounter III Neck | Activity | Every 2 h | Heat
Axel Collar | Medria Inc. | FR | Farm’Life® | ○ | 100 × 48 × 30 | 160 | - | 1000 | Accelerometer | Axel Collar (Feed’Live/Heat’Live/Time’Live) | High activity/Inactivity/Ruminating time/Eating time/Lying time/Standing time | - | Heat/Health disorder
Smart Collar | HerdInsights | IE | HerdInsights Software | ○ | - | - | 5 years | - | Accelerometer | Smart Collar | Activity/Inactivity/Ruminating time/Eating time/Heat index | Every hour | Heat/Health disorder
Moocall Heat | Moocall Ltd. | IE | Moocall Breedmanager | ○ | - | - | 60 days | 3G coverage | - | Moocall Heat | - | - | Heat
MooMonitor+ | Dairy Master | IE | Dairymaster MooMonitor | ○ | - | - | 10 years | 1000 | Accelerometer | MooMonitor+ | High activity/Activity/Low activity/Inactivity/Ruminating time/Eating time | Every hour | Heat/Health disorder
SmartTag Neck | Pearson International LLC | IE | Pearson Heat Detection with Health Monitoring system | ○ | - | - | 10 years | - | Accelerometer | SmartTag Neck | Eating time/Not eating time | - | Heat/Health disorder
cSense Flex tag | SCR Engineers Ltd. (Allflex Europe SA) | IL | SenseHub™ Dairy/SenseHub™ Beef/ Heatime® Pro+ System | ○ | 84 × 64 | 98 | 7 years | 200 × 500 * | Accelerometer | cSense Flex tag | Activity/Ruminating time/Heat index | Every 2 h | Heat/Health disorder
SCR H-LD | SCR Engineers Ltd. (Allflex Europe SA) | IL | Heatime® HR System (Independent device)/ Heatime® Pro+ System (PC) | ○ | 84.1 × 64.5 | 98 | 7 years | 200 × 500 * | Accelerometer | SCR H-LD | Activity/Heat index | Every 2 h | Heat/Health disorder
SCR HR-LD/SCR HR-LDn | SCR Engineers Ltd.(Allflex Europe SA) | IL | Heatime® HR System(Independent device)/Heatime® Pro+ System (PC) | ○ | 84.1 × 64.5 | 98 | 7 years | 200 × 500 * | Accelerometer/Microphone | SCR HR-LD /SCR HR-LDn | Activity/Ruminating time/Heat index | Every 2 h | Heat/Health disorder
Qwes ISO LD/LD Smarttag | Lely | IL | Lely T4C management system | ○ | - | - | - | 75 | Accelerometer | Qwes ISO LD Smarttag (CowLocator) | Activity/Ruminating time/(Location) | Every 2 h | Heat/Health disorder
Qwes H-LD | Lely | IL | Lely T4C management system | ○ | - | - | - | 500 | Accelerometer | Qwes H-LD | Activity | Every 2 h | Heat
Qwes HR-LDn | Lely | IL | Lely T4C management system | ○ | - | - | - | 500 | Accelerometer/Microphone | Qwes HR-LDn | Activity/Ruminating time | Every 2 h | Heat/Health disorder
AfiCollar | Afimilk Agricultural Cooperative Ltd. | IL | AfiFarm Software/Afi2Go Pro Mobile App | ○ | - | - | - | 200–800 | Accelerometer | AfiCollar | Activity/Ruminating time/Eating time | - | Heat/Health disorder
Milkrite|InterPuls Neck Tag | milkrite | InterPuls | IT | MyFarm | ○ | - | - | - | 75–500 | Accelerometer | Milkrite|InterPuls Neck Tag | Activity/Ruminating time/Eating time/Location | - | Heat/Health disorder
Smarttag Neck | Nedap livestock management | NL | Nedap CowControl | ○ | - | - | 10 years | 75 | Accelerometer | Smarttag Neck (Cow positioning) | Activity/Inactivity/Ruminating time/Eating time/Eating bouts/(Location) | Continuously | Heat/Health disorder
Smarttag Neck/All in One | CRV international B.V. | NL | Ovalert | ○ | - | - | - | - | Accelerometer | Smarttag All in One (Cow positioning) | Inactivity/Ruminating time/Eating time/Not eating time/(Location) | Continuously | Heat/Health disorder
Activity meter system | DeLaval International AB Inc. | SE | AlPro/DelPro Farm Management systems | ○ | - | 170 | 10 years | 200 | Accelerometer | Activity meter system | Activity/Heat index | Every hour | Heat/Health disorder
Cowlar | Cowlar | US | Cowlar | × | 110 × 62 × 33 | 242 | 6 months | >3000 | Accelerometer/Temperature sensor | Cowlar | Activity/Ruminating time/Eating time/Step counts | - | Heat/Health disorder
HeatSeeker II Neck | BouMatic LLC | US | HerdMetrix™ | ○ | - | 135 | 7 years | 100–750 | Accelerometer | HeatSeeker II Neck | Activity | Every 2 h | Heat
RealTime SmartTag | BouMatic LLC | US | HerdMetrix™ | ○ | - | - | - | - | Accelerometer | RealTime SmartTag (Activity/Rumination & Localization) | Activity/Inactivity/Ruminating time/Eating time/(Location) | Every 2 h | Heat/Health disorder
* Area coverage.

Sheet: Accelerometer
Part # (https://eu.mouser.com/c/sensors/motion-position-sensors/accelerometers/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) | Mfr. (https://eu.mouser.com/c/sensors/motion-position-sensors/accelerometers/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) | Description | Datasheet | Availability | Pricing (EUR)Filter the results in the table by unit price based on your quantity. | Sensors | Qty. | RoHS | ECAD Model | Acceleration (https://eu.mouser.com/c/sensors/motion-position-sensors/accelerometers/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) | Full Power Mode Operating Supply Current | Lowest Power Mode Current | Sleep Mode Current | Output Type (https://eu.mouser.com/c/sensors/motion-position-sensors/accelerometers/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) | Output Resolution | Sensitivity (https://eu.mouser.com/c/sensors/motion-position-sensors/accelerometers/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) | Supply Voltage - Min (https://eu.mouser.com/c/sensors/motion-position-sensors/accelerometers/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) | Supply Voltage - Max | Sensor Type (https://eu.mouser.com/c/sensors/motion-position-sensors/accelerometers/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) | Sensing Axis (https://eu.mouser.com/c/sensors/motion-position-sensors/accelerometers/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) | Interface Type (https://eu.mouser.com/c/sensors/motion-position-sensors/accelerometers/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) | Minimum Operating Temperature (https://eu.mouser.com/c/sensors/motion-position-sensors/accelerometers/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) | Maximum Operating Temperature (https://eu.mouser.com/c/sensors/motion-position-sensors/accelerometers/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) | Mounting Style (https://eu.mouser.com/c/sensors/motion-position-sensors/accelerometers/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) | Package/Case (https://eu.mouser.com/c/sensors/motion-position-sensors/accelerometers/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) | Packaging (https://eu.mouser.com/c/sensors/motion-position-sensors/accelerometers/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) | Auxiliary ADC | Features | Type
RECOMMENDED |  |  |  |  |  |  |  |  |  | between 0.5 g and 2.5 g, with 1 g being the most common a wider range such 4g to accommodate other potential use cases or animals. | Board: 500mA or below |  |  | Analog | 12-bit or above | 0.244 mg/digit to 7.808 mg/digit 0.98 mg/digit, 1.95 mg/digit, 3.91 mg/digit 1 mg/digit to 12 mg/digit 1 mg/digit to 192 mg/digit 4 mg/digit, 8 mg/digit, 16 mg/digit, 48 mg/digit | 3.3V or below |  | 3-axis | X,Y,Z | I2C
Mfr. Part No. LIS3DHHTR Mouser Part No 511-LIS3DHHTR (https://eu.mouser.com/ProductDetail/STMicroelectronics/LIS3DHHTR?qs=YOlfkO5Tc8hAGikNVY3R9g%3D%3D) | STMicroelectronics (https://eu.mouser.com/manufacturer/stmicroelectronics/) | Accelerometers 3-axis accelerometer, ultra high resolution, low-noise, SPI 4-wire digital outpuLearn More (https://eu.mouser.com/new/stmicroelectronics/stm-lis3dhh-accelerometer/) | Datasheet (https://eu.mouser.com/datasheet/2/389/lis3dhh-1849590.pdf) | 2.774In Stock | Cut Tape 1:14,63 € 10:11,94 € 25:11,05 € 50:10,74 € 100:View Reel 3.000:7,95 € MouseReel Available (https://eu.mouser.com/ProductDetail/STMicroelectronics/LIS3DHHTR?qs=YOlfkO5Tc8hAGikNVY3R9g%3D%3D) |  | Buy Min.: 1 Mult.: 1 Reel: 3.000 | Details (https://eu.mouser.com/Search/CompliantByExemption?qs=RYdJ1mvGF47DaCNo%2BGeSAA==) |  | 2.5 g | 5 mA |  |  | Analog / Digital | 16 bit | 1 mg/digit to 12 mg/digit | 1.71 V | 3.6 V | 3-axis | X, Y, Z | I2C, SPI | - 40 C | 85 C | SMD/SMT | LGA-16 | Reel, Cut Tape, MouseReel
Mfr. Part No. LIS2DTW12TR Mouser Part No 511-LIS2DTW12TR (https://eu.mouser.com/ProductDetail/STMicroelectronics/LIS2DTW12TR?qs=vLWxofP3U2wWQNJUyb0PcA%3D%3D) | STMicroelectronics (https://eu.mouser.com/manufacturer/stmicroelectronics/) | Accelerometers MEMS digital output dual motion and temperature sensorLearn More (https://eu.mouser.com/new/stmicroelectronics/stm-lis2d/) | Datasheet (https://eu.mouser.com/datasheet/2/389/lis2dtw12-1545785.pdf) | 18.217In Stock | Cut Tape 1:3,95 € 10:3,49 € 25:2,50 € 100:2,43 € 500:View Reel 10.000:1,88 € MouseReel Available (https://eu.mouser.com/ProductDetail/STMicroelectronics/LIS2DTW12TR?qs=vLWxofP3U2wWQNJUyb0PcA%3D%3D) |  | Buy Min.: 1 Mult.: 1 Reel: 10.000 | Details (https://eu.mouser.com/Search/RoHSCompliant?qs=erF4vec4Rjp18uN5pF3t8g==) |  | 2 g, 4 g, 8 g, 16 g | 90 uA |  |  | Digital | 16 bit | 0.244 mg/digit to 7.808 mg/digit | 1.62 V | 3.6 V | 3-axis | X, Y, Z | I2C, SPI | - 40 C | 85 C | SMD/SMT | LGA-12 | Reel, Cut Tape, MouseReel
Mfr. Part No. IIS328DQTR Mouser Part No 511-IIS328DQTR (https://eu.mouser.com/ProductDetail/STMicroelectronics/IIS328DQTR?qs=v3MacVxtdDJzgatCuHTcWQ%3D%3D) | STMicroelectronics (https://eu.mouser.com/manufacturer/stmicroelectronics/) | Accelerometers High-performance ultra-low-power 3-axis accelerometer digital output for industrLearn More (https://eu.mouser.com/new/stmicroelectronics/stm-iis328dq-accelerometer/) | Datasheet (https://eu.mouser.com/datasheet/2/389/iis328dq-1849367.pdf) | 33.735In StockAlternative Packaging (https://eu.mouser.com/Search/AlternatePackagingPopUp) | Cut Tape 1:6,23 € 10:5,51 € 25:3,95 € 100:3,84 € 500:View Reel 3.000:2,90 € MouseReel Available (https://eu.mouser.com/ProductDetail/STMicroelectronics/IIS328DQTR?qs=v3MacVxtdDJzgatCuHTcWQ%3D%3D) |  | Buy Min.: 1 Mult.: 1 Reel: 3.000 | Details (https://eu.mouser.com/Search/RoHSCompliant?qs=ufmVeds%2BQH%2BXXVEMfrV6/A==) |  | 2 g, 4 g, 8 g | 250 uA |  |  | Digital | 16 bit | 0.98 mg/digit, 1.95 mg/digit, 3.91 mg/digit | 2.16 V | 3.6 V | 3-axis | X, Y, Z | I2C, SPI | - 40 C | 105 C | SMD/SMT | QFN-24 | Reel, Cut Tape, MouseReel
Mfr. Part No. LIS2DH12TR Mouser Part No 511-LIS2DH12TR (https://eu.mouser.com/ProductDetail/STMicroelectronics/LIS2DH12TR?qs=yXzv9R%2FF42K6DbawEx3XmQ%3D%3D) | STMicroelectronics (https://eu.mouser.com/manufacturer/stmicroelectronics/) | Accelerometers MEMS digital output motion sensor: ultra-low-power high-performance 3-axis "femtLearn More (https://eu.mouser.com/new/stmicroelectronics/stm-lis2d/) | Datasheet (https://eu.mouser.com/datasheet/2/389/lis2dh12-1849850.pdf) | 151.292In StockAlternative Packaging (https://eu.mouser.com/Search/AlternatePackagingPopUp) | Cut Tape 1:2,36 € 10:1,86 € 25:1,49 € 100:1,34 € 250:View Reel 8.000:0,949 € MouseReel Available (https://eu.mouser.com/ProductDetail/STMicroelectronics/LIS2DH12TR?qs=yXzv9R%2FF42K6DbawEx3XmQ%3D%3D) |  | Buy Min.: 1 Mult.: 1 Reel: 8.000 | Details (https://eu.mouser.com/Search/CompliantByExemption?qs=MwYkxz09MvNPbCp8wXrYmQ==) |  | 2 g, 4 g, 8 g, 16 g | 11 uA |  |  | Digital | 12 bit | 1 mg/digit to 192 mg/digit | 1.71 V | 3.6 V | 3-axis | X, Y, Z | I2C, SPI | - 40 C | 85 C | SMD/SMT | LGA-12 | Reel, Cut Tape, MouseReel
Mfr. Part No. LIS2DHTR Mouser Part No 511-LIS2DHTR End of Life (https://eu.mouser.com/ProductDetail/STMicroelectronics/LIS2DHTR?qs=Pac2tMOelJCzRxWPjYnq1w%3D%3D) | STMicroelectronics (https://eu.mouser.com/manufacturer/stmicroelectronics/) | Accelerometers MEMS 3-Axis Femto 1.71 to 3.6V 2uA LPLearn More (https://eu.mouser.com/new/stmicroelectronics/stm-lis2d/) | Datasheet (https://eu.mouser.com/datasheet/2/389/lis2dh-1849698.pdf) | 6.915In StockAlternative Packaging (https://eu.mouser.com/Search/AlternatePackagingPopUp) | Cut Tape 1:2,71 € 10:2,09 € 25:1,74 € 100:1,47 € 500:View Reel 8.000:1,07 € MouseReel Available (https://eu.mouser.com/ProductDetail/STMicroelectronics/LIS2DHTR?qs=Pac2tMOelJCzRxWPjYnq1w%3D%3D) |  | Buy Min.: 1 Mult.: 1 Reel: 8.000 | Details (https://eu.mouser.com/Search/CompliantByExemption?qs=7ATk1dR5Vvtetp1bE2vFHw==) |  | 2 g, 4 g, 8 g, 16 g | 2 uA |  |  | Digital | 12 bit | 4 mg/digit, 8 mg/digit, 16 mg/digit, 48 mg/digit | 1.71 V | 3.6 V | 3-axis | X, Y, Z | I2C, SPI | - 40 C | 85 C | SMD/SMT | LGA-14 | Reel, Cut Tape, MouseReel
MPU6050 |  |  | https://invensense.tdk.com/wp-content/uploads/2015/02/MPU-6000-Datasheet1.pdf | https://2betrading.com/accueil/1774-mpu6050-mpu-6050-gy-521-module-3-axes-gyro-3-axes-accelerometer.html | 8,700 TND | Accel + Gyro |  |  |  | ±2 ±4 ±8 ±16 | 500µA (accel only) | 10µA at 1Hz | 5µA | Digital | 16-bit | 2g: 16,384 LSB/g 4g: 8,192 LSB/g 8g: 4,096 LSB/g 16g: 2,048 LSB/g | 2.375V | 3.46V | 3-axis | X, Y, Z | 400kHz Fast Mode I²C | - 40 C | 85 C |  |  |  | NA | Digital-output temperature sensor 10,000g shock tolerant Orientation detection and signaling Tap detection User-programmable interrupts High-G interrupt User self-test | MEMS
ADXL345 |  |  | https://www.analog.com/media/en/technical-documentation/data-sheets/adxl345.pdf | https://seli.tn/page1?recherche=accelerometre | 12.000 TND | Accel |  |  |  | ±2 g/±4 g/±8 g/±16 g | 140µA | 23 µA | 0.1 µA | Digital | Fixed 10-bit resolution ► Full resolution, where resolution increases with g range, up to 13-bit resolution at ±16 g (maintaining 4 mg/LSB scale factor in all g ranges) | 2g: 256 LSB/g 4g: 128 LSB/g 8g: 64 LSB/g 16g: 32 LSB/g | 2.0 V | 3.46V | 3-axis | X, Y, Z | I2C/SPI | - 40 C | 85 C |  |  |  | NA | ► Embedded memory management system with FIFO technology minimizes host processor load ► Single tap/double tap detection ► Activity/inactivity monitoring ► Free-fall detection Flexible interrupt modes mappable to either interrupt pin ► Measurement ranges selectable via serial command ► Bandwidth selectable via serial command ► 10,000 g shock survival ► Pb free/RoHS compliant ► Small and thin: 3 mm × 5 mm × 1 mm LGA package | MEMS
MMA7455L |  |  | https://www.nxp.com/docs/en/data-sheet/MMA7455L.pdf | https://2betrading.com/capteurs/46-mma7455l-3-axis-low-g-digital-output-accelerometer.html | 19,000 TND | Accel |  |  |  | ±2g/±4g/±8g | 490µA |  | 10µA | Digital | 8-bit (2g,4g), 10-bit (8g) | 2g: 64 LSB/g 4g: 32 LSB/g 8g: 16 LSB/g | 2.4 V | 3.6 V | 3-axis | X, Y, Z | I2C/SPI | - 40 C | 85 C |  |  |  | NA | Self-Test for Z-Axis User Assigned Registers for Offset Calibration • Programmable Threshold Interrupt Output • Level Detection for Motion Recognition (Shock, Vibration, Freefall) • Pulse Detection for Single or Double Pulse Recognition • Robust Design, High Shocks Survivability (5,000g) • Low Cost | MEMS
LIS2DH | Gravity |  | https://www.st.com/resource/en/datasheet/lis2dh.pdf | https://2betrading.com/cartes-de-developpement/1484-gravity-i2c-triple-axis-accelerometer-lis2dh.html | 20,469 TND | Accel |  |  |  | ±2g/±4g/±8g/±16g | 11µA in 50 Hz | 2 μA | 0.5µA | Digital | 8-bit (low power) 10-bit (normal power) 12-bit (high resolution) | High resolution: 2g, 1 mg/digit: 512 LSB/g 4g, 2 mg/digit: 128 LSB/g 8g, 4 mg/digit: 32 LSB/g 16g, 12 mg/digit: 5.33 LSB/g normal power: 2g, 1 mg/digit: 128 LSB/g 4g, 2 mg/digit: 32 LSB/g 8g, 4 mg/digit: 8 LSB/g 16g, 12 mg/digit: 1.33 LSB/g low power 2g, 1 mg/digit: 32 LSB/g 4g, 2 mg/digit: 8 LSB/g 8g, 4 mg/digit: 2 LSB/g 16g, 12 mg/digit: 0.33 LSB/g | 1.71 V | 3.6 V | 3-axis | X, Y, Z | I2C/SPI | - 40 C | 85 C |  |  |  | NA | 2 independent programmable interrupt generators for free-fall and motion detection 6D/4D orientation detection “Sleep to wake” and “return to sleep” function Freefall detection Motion detection Embedded temperature sensor Embedded FIFO ECOPACK® RoHS and “Green” compliant | MEMS
ADXL335 |  |  | https://www.analog.com/media/en/technical-documentation/data-sheets/ADXL335.pdf | https://seli.tn/page1?recherche=accelerometre | 25.000 TND | Accel + Gyro |  |  |  | ±3 g | 350 μA | 200 μA | NA | analog | 10-bit | 3g: 306.96 LSB/g. | 1.8 V | 3.6 V | 3-axis | X, Y, Z | NA | - 40 C | 85 C |  |  |  | NA | 10,000 g shock survival Excellent temperature stability BW adjustment with a single capacitor per axis RoHS/WEEE lead-free compliant
MPU-6500 |  |  | https://invensense.tdk.com/wp-content/uploads/2020/06/PS-MPU-6500A-01-v1.3.pdf | https://seli.tn/page1?recherche=accelerometre | 30.000 TND | Accel + Gyro |  |  |  | ±2 ±4 ±8 ±16 | 450µA (accel only) 3.4mA (all) | 6.37µA at 0.98Hz, | 6 μA | Digital | 16-bit | 2g: 16,384 LSB/g 4g: 8,192 LSB/g 8g: 4,096 LSB/g 16g: 2,048 LSB/g | 1.8V | 3.3 V | 3-axis | X, Y, Z | 400kHz Fast Mode I2 C for communicating with all registers • 1MHz SPI serial interface for communicating with all registers • 20MHz SPI serial interface for reading sensor and interrupt registers | - 40 C | 85 C |  |  |  | NA | User-programmable interrupts • Wake-on-motion interrupt for low power operation of applications processor • Self-test Auxiliary master I2C bus for reading data from external sensors (e.g. magnetometer) Smallest and thinnest QFN package for portable devices: 3x3x0.9mm • Minimal cross-axis sensitivity between the accelerometer and gyroscope axes • 512 byte FIFO buffer enables the applications processor to read the data in bursts • Digital-output temperature sensor • User-programmable digital filters for gyroscope, accelerometer, and temp sensor • 10,000 g shock tolerant RoHS and Green compliant Temperature sensor | MEMS
LIS3DH | Adafruit |  | https://www.st.com/resource/en/datasheet/lis3dh.pdf | https://2betrading.com/accueil/6634-adafruit-lis3dh-triple-axis-accelerometer.html | 38000 | Accel |  |  |  | 2g/±4g/8g/16g | 11µA in 50 Hz | 2 μA | 0.5µA | Digital | "8-bit (low power) 10-bit (normal power) 12-bit (high resolution) 16-bit output available | High resolution: 2g, 1 mg/digit: 512 LSB/g 4g, 2 mg/digit: 128 LSB/g 8g, 4 mg/digit: 32 LSB/g 16g, 12 mg/digit: 5.33 LSB/g normal power: 2g, 1 mg/digit: 128 LSB/g 4g, 2 mg/digit: 32 LSB/g 8g, 4 mg/digit: 8 LSB/g 16g, 12 mg/digit: 1.33 LSB/g low power 2g, 1 mg/digit: 32 LSB/g 4g, 2 mg/digit: 8 LSB/g 8g, 4 mg/digit: 2 LSB/g 16g, 12 mg/digit: 0.33 LSB/g | 1.71 V | 3.6 V | 3-axis | X, Y, Z | I2C/SPI | - 40 C | 85 C |  |  |  | 3x 10-bit | 2 independent programmable interrupt generators for free-fall and motion detection 6D/4D orientation detection Free-fall detection Motion detection Embedded temperature sensor Embedded self-test Embedded 32 levels of 16-bit data output FIFO 10000 g high shock survivability ECOPACK®, RoHS and “Green” compliant | MEMS
MMA7361L |  |  | https://www.nxp.com/docs/en/data-sheet/MMA7361L.pdf | https://2betrading.com/accueil/889-triple-axis-accelerometer-breakout-mma7361l.html | 39,507 TND | Accel |  |  |  | ±1.5g, ±6g | 600 μA | 400 μA | 3 μA | Analog | NA | 1.5g: 643.75 LSB/g 6g: 88.04 LSB/g | 2.2 V | 3.6 V | 3-axis | X, Y, Z | NA | - 40 C | 85 C |  |  |  | NA | Fast Turn On Time (0.5 ms Enable Response Time) • Self Test for Freefall Detect Diagnosis • 0g-Detect for Freefall Protection • Signal Conditioning with Low Pass Filter • Robust Design, High Shocks Survivability • RoHS Compliant • Environmentally Preferred Product • Low Cost
MPU9250 |  |  | https://invensense.tdk.com/wp-content/uploads/2015/02/PS-MPU-9250A-01-v1.1.pdf | https://seli.tn/page1?recherche=accelerometre | 40.000 TND | Accel + Gyro + Magneto |  |  |  | ±2 ±4 ±8 ±16 | 450µA (accel only) 3.5mA (all) | 8.4µA at 0.98Hz (accel only) | 8 μA | Digital | 16-bit | 2g: 16,384 LSB/g 4g: 8,192 LSB/g 8g: 4,096 LSB/g 16g: 2,048 LSB/g | 2.4V | 3.6 V | 3-axis | X, Y, Z | 400kHz Fast Mode I2C for communicating with all registers 1MHz SPI serial interface for communicating with all registers | - 40 C | 85 C |  |  |  | NA | User-programmable interrupts Wake-on-motion interrupt for low power operation of applications processor Self-test Auxiliary master I2C bus for reading data from external sensors (e.g. pressure sensor) VDDIO reference voltage for auxiliary I2C devices Smallest and thinnest QFN package for portable devices: 3x3x1mm Minimal cross-axis sensitivity between the accelerometer, gyroscope and magnetometer axes 512 byte FIFO buffer enables the applications processor to read the data in bursts Digital-output temperature sensor User-programmable digital filters for gyroscope, accelerometer, and temp sensor | MEMS
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

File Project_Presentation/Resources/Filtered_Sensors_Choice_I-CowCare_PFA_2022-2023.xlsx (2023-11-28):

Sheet: Ear-tag
Information about currently available ear-tag and halter type sensor.
Product | Company (Parent Company) | Country | Management Software | Mobile Application | Dimensions (mm × mm × mm) | Weight (g) | Battery Life | Range (m) | Built-in Sensors | Output Data | Data Reporting Frequency | Detection
Ear tag
Smartbow | Smartbow GmbH (Zoetis Services LLC.) | AT | Herd Monitoring Software | ○ | 52 × 36 × 17 | 34 | 2 years | 300 | Accelerometer Temperature sensor | High activity/Activity/Inactivity/Ruminating time/Location | Every hour | Heat/Health disorder
eSense Flex tag | SCR Engineers Ltd. (Allflex Europe SA) | IL | SenseHub™/ Heatime® Pro+ | ○ | 68 × 38 × 15 | 25 | 3 years | 200 × 500 * | Accelerometer | Activity/Ruminating time/Heat index | Every 2 h | Heat/Health disorder
CowManager SensOor | Agis Automatisering BV | NL | CowManager System | ○ | 60 × 50 × 22 | 32 | 5 years | - | Accelerometer Temperature sensor | High activity/Activity/Inactivity/Ruminating time/Eating time/Temperature/(Location) | Every hour | Heat/Health disorder
TekSensor tag | TekVet Technologies Co. | NL | TekAccess™ | × | - | - | - | - | Temperature sensor | Temperature | Every hour | Health disorder
Calf Tag | FeverTags LLC | US | TempVerified | × | - | 14 | 2 years | - | Temperature sensor | Temperature | Every 15 min | Health disorder
Data Collection Tag | FeverTags LLC | US | - | × | - | - | - | - | Temperature sensor | Temperature | Every 15 min | Research purpose (Data acquisition only)
Halter
RumiWatch Noseband Sensor | ITIN + HOCH GmbH | CH | RumiWatch Manager/RumiWatch Converter | × | - | - | 2 years | - | Accelerometer Temperature sensorPressure sensor | Raw activity/Other chewing activity/Ruminating time/Regurgitated boli counts/Ruminating chew counts/Chews per bolus/Chews per minute/Eating time/Eating chew counts/Drinking time/Drinking gulp count/Temperature (ambient) | Every minute /Every hour | Research purpose (Data acquisition only)
* Area coverage.

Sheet: Neck collar type sensor
Product | Company (Parent Company) | Country | Dimensions (mm × mm × mm) | Weight (g) | Battery Life | Range (m) | Built-In Sensors | Output Data | Data Reporting Frequency | Detection
CowScout Neck | GEA Farm Technologies, Inc. | DE | - | - | 5 years | 100–1000 | Accelerometer | Activity/Inactivity/Ruminating time/Eating time | Every 2 h | Heat/Health disorder
Axel Collar | Medria Inc. | FR | 100 × 48 × 30 | 160 | - | 1000 | Accelerometer | High activity/Inactivity/Ruminating time/Eating time/Lying time/Standing time | - | Heat/Health disorder
Smart Collar | HerdInsights | IE | - | - | 5 years | - | Accelerometer | Activity/Inactivity/Ruminating time/Eating time/Heat index | Every hour | Heat/Health disorder
Moocall Heat | Moocall Ltd. | IE | - | - | 60 days | 3G coverage | - | - | - | Heat
MooMonitor+ | Dairy Master | IE | - | - | 10 years | 1000 | Accelerometer | High activity/Activity/Low activity/Inactivity/Ruminating time/Eating time | Every hour | Heat/Health disorder

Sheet: Accelerometer
Part # (https://eu.mouser.com/c/sensors/motion-position-sensors/accelerometers/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) | Mfr. (https://eu.mouser.com/c/sensors/motion-position-sensors/accelerometers/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) | Pricing (EUR)Filter the results in the table by unit price based on your quantity. | Sensors | Type | Acceleration (https://eu.mouser.com/c/sensors/motion-position-sensors/accelerometers/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) | Full Power Mode Operating Supply Current | Lowest Power Mode Current | Sleep Mode Current | Output Type (https://eu.mouser.com/c/sensors/motion-position-sensors/accelerometers/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) | Output Resolution | Sensitivity (https://eu.mouser.com/c/sensors/motion-position-sensors/accelerometers/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) | Supply Voltage - Min (https://eu.mouser.com/c/sensors/motion-position-sensors/accelerometers/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) | Supply Voltage - Max | Sensor Type (https://eu.mouser.com/c/sensors/motion-position-sensors/accelerometers/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) | Sensing Axis (https://eu.mouser.com/c/sensors/motion-position-sensors/accelerometers/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) | Interface Type (https://eu.mouser.com/c/sensors/motion-position-sensors/accelerometers/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) | Minimum Operating Temperature (https://eu.mouser.com/c/sensors/motion-position-sensors/accelerometers/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) | Maximum Operating Temperature (https://eu.mouser.com/c/sensors/motion-position-sensors/accelerometers/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) | Features | Sock Tolerance | Qty. | RoHS | ECAD Model | Auxiliary ADC | Mounting Style (https://eu.mouser.com/c/sensors/motion-position-sensors/accelerometers/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) | Package/Case (https://eu.mouser.com/c/sensors/motion-position-sensors/accelerometers/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) | Packaging (https://eu.mouser.com/c/sensors/motion-position-sensors/accelerometers/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) | Description | Datasheet | Availability
RECOMMENDED |  |  |  |  | between 0.5 g and 2.5 g, with 1 g being the most common a wider range such 4g to accommodate other potential use cases or animals. | Board: 500mA or below |  |  | Analog | 12-bit or above | 0.244 mg/digit to 7.808 mg/digit 0.98 mg/digit, 1.95 mg/digit, 3.91 mg/digit 1 mg/digit to 12 mg/digit 1 mg/digit to 192 mg/digit 4 mg/digit, 8 mg/digit, 16 mg/digit, 48 mg/digit | 3.3V or below |  | 3-axis | X,Y,Z | I2C
Mfr. Part No. LIS3DHHTR Mouser Part No 511-LIS3DHHTR (https://eu.mouser.com/ProductDetail/STMicroelectronics/LIS3DHHTR?qs=YOlfkO5Tc8hAGikNVY3R9g%3D%3D) | STMicroelectronics (https://eu.mouser.com/manufacturer/stmicroelectronics/) | Cut Tape 1:14,63 € 10:11,94 € 25:11,05 € 50:10,74 € 100:View Reel 3.000:7,95 € MouseReel Available (https://eu.mouser.com/ProductDetail/STMicroelectronics/LIS3DHHTR?qs=YOlfkO5Tc8hAGikNVY3R9g%3D%3D) |  |  | 2.5 g | 5 mA |  |  | Analog / Digital | 16 bit | 1 mg/digit to 12 mg/digit | 1.71 V | 3.6 V | 3-axis | X, Y, Z | I2C, SPI | - 40 C | 85 C |  |  | Buy Min.: 1 Mult.: 1 Reel: 3.000 | Details (https://eu.mouser.com/Search/CompliantByExemption?qs=RYdJ1mvGF47DaCNo%2BGeSAA==) |  |  | SMD/SMT | LGA-16 | Reel, Cut Tape, MouseReel | Accelerometers 3-axis accelerometer, ultra high resolution, low-noise, SPI 4-wire digital outpuLearn More (https://eu.mouser.com/new/stmicroelectronics/stm-lis3dhh-accelerometer/) | Datasheet (https://eu.mouser.com/datasheet/2/389/lis3dhh-1849590.pdf) | 2.774In Stock
Mfr. Part No. LIS2DTW12TR Mouser Part No 511-LIS2DTW12TR (https://eu.mouser.com/ProductDetail/STMicroelectronics/LIS2DTW12TR?qs=vLWxofP3U2wWQNJUyb0PcA%3D%3D) | STMicroelectronics (https://eu.mouser.com/manufacturer/stmicroelectronics/) | Cut Tape 1:3,95 € 10:3,49 € 25:2,50 € 100:2,43 € 500:View Reel 10.000:1,88 € MouseReel Available (https://eu.mouser.com/ProductDetail/STMicroelectronics/LIS2DTW12TR?qs=vLWxofP3U2wWQNJUyb0PcA%3D%3D) |  |  | 2 g, 4 g, 8 g, 16 g | 90 uA |  |  | Digital | 16 bit | 0.244 mg/digit to 7.808 mg/digit | 1.62 V | 3.6 V | 3-axis | X, Y, Z | I2C, SPI | - 40 C | 85 C |  |  | Buy Min.: 1 Mult.: 1 Reel: 10.000 | Details (https://eu.mouser.com/Search/RoHSCompliant?qs=erF4vec4Rjp18uN5pF3t8g==) |  |  | SMD/SMT | LGA-12 | Reel, Cut Tape, MouseReel | Accelerometers MEMS digital output dual motion and temperature sensorLearn More (https://eu.mouser.com/new/stmicroelectronics/stm-lis2d/) | Datasheet (https://eu.mouser.com/datasheet/2/389/lis2dtw12-1545785.pdf) | 18.217In Stock
Mfr. Part No. IIS328DQTR Mouser Part No 511-IIS328DQTR (https://eu.mouser.com/ProductDetail/STMicroelectronics/IIS328DQTR?qs=v3MacVxtdDJzgatCuHTcWQ%3D%3D) | STMicroelectronics (https://eu.mouser.com/manufacturer/stmicroelectronics/) | Cut Tape 1:6,23 € 10:5,51 € 25:3,95 € 100:3,84 € 500:View Reel 3.000:2,90 € MouseReel Available (https://eu.mouser.com/ProductDetail/STMicroelectronics/IIS328DQTR?qs=v3MacVxtdDJzgatCuHTcWQ%3D%3D) |  |  | 2 g, 4 g, 8 g | 250 uA |  |  | Digital | 16 bit | 0.98 mg/digit, 1.95 mg/digit, 3.91 mg/digit | 2.16 V | 3.6 V | 3-axis | X, Y, Z | I2C, SPI | - 40 C | 105 C |  |  | Buy Min.: 1 Mult.: 1 Reel: 3.000 | Details (https://eu.mouser.com/Search/RoHSCompliant?qs=ufmVeds%2BQH%2BXXVEMfrV6/A==) |  |  | SMD/SMT | QFN-24 | Reel, Cut Tape, MouseReel | Accelerometers High-performance ultra-low-power 3-axis accelerometer digital output for industrLearn More (https://eu.mouser.com/new/stmicroelectronics/stm-iis328dq-accelerometer/) | Datasheet (https://eu.mouser.com/datasheet/2/389/iis328dq-1849367.pdf) | 33.735In StockAlternative Packaging (https://eu.mouser.com/Search/AlternatePackagingPopUp)
Mfr. Part No. LIS2DH12TR Mouser Part No 511-LIS2DH12TR (https://eu.mouser.com/ProductDetail/STMicroelectronics/LIS2DH12TR?qs=yXzv9R%2FF42K6DbawEx3XmQ%3D%3D) | STMicroelectronics (https://eu.mouser.com/manufacturer/stmicroelectronics/) | Cut Tape 1:2,36 € 10:1,86 € 25:1,49 € 100:1,34 € 250:View Reel 8.000:0,949 € MouseReel Available (https://eu.mouser.com/ProductDetail/STMicroelectronics/LIS2DH12TR?qs=yXzv9R%2FF42K6DbawEx3XmQ%3D%3D) |  |  | 2 g, 4 g, 8 g, 16 g | 11 uA |  |  | Digital | 12 bit | 1 mg/digit to 192 mg/digit | 1.71 V | 3.6 V | 3-axis | X, Y, Z | I2C, SPI | - 40 C | 85 C |  |  | Buy Min.: 1 Mult.: 1 Reel: 8.000 | Details (https://eu.mouser.com/Search/CompliantByExemption?qs=MwYkxz09MvNPbCp8wXrYmQ==) |  |  | SMD/SMT | LGA-12 | Reel, Cut Tape, MouseReel | Accelerometers MEMS digital output motion sensor: ultra-low-power high-performance 3-axis "femtLearn More (https://eu.mouser.com/new/stmicroelectronics/stm-lis2d/) | Datasheet (https://eu.mouser.com/datasheet/2/389/lis2dh12-1849850.pdf) | 151.292In StockAlternative Packaging (https://eu.mouser.com/Search/AlternatePackagingPopUp)
Mfr. Part No. LIS2DHTR Mouser Part No 511-LIS2DHTR End of Life (https://eu.mouser.com/ProductDetail/STMicroelectronics/LIS2DHTR?qs=Pac2tMOelJCzRxWPjYnq1w%3D%3D) | STMicroelectronics (https://eu.mouser.com/manufacturer/stmicroelectronics/) | Cut Tape 1:2,71 € 10:2,09 € 25:1,74 € 100:1,47 € 500:View Reel 8.000:1,07 € MouseReel Available (https://eu.mouser.com/ProductDetail/STMicroelectronics/LIS2DHTR?qs=Pac2tMOelJCzRxWPjYnq1w%3D%3D) |  |  | 2 g, 4 g, 8 g, 16 g | 2 uA |  |  | Digital | 12 bit | 4 mg/digit, 8 mg/digit, 16 mg/digit, 48 mg/digit | 1.71 V | 3.6 V | 3-axis | X, Y, Z | I2C, SPI | - 40 C | 85 C |  |  | Buy Min.: 1 Mult.: 1 Reel: 8.000 | Details (https://eu.mouser.com/Search/CompliantByExemption?qs=7ATk1dR5Vvtetp1bE2vFHw==) |  |  | SMD/SMT | LGA-14 | Reel, Cut Tape, MouseReel | Accelerometers MEMS 3-Axis Femto 1.71 to 3.6V 2uA LPLearn More (https://eu.mouser.com/new/stmicroelectronics/stm-lis2d/) | Datasheet (https://eu.mouser.com/datasheet/2/389/lis2dh-1849698.pdf) | 6.915In StockAlternative Packaging (https://eu.mouser.com/Search/AlternatePackagingPopUp)
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

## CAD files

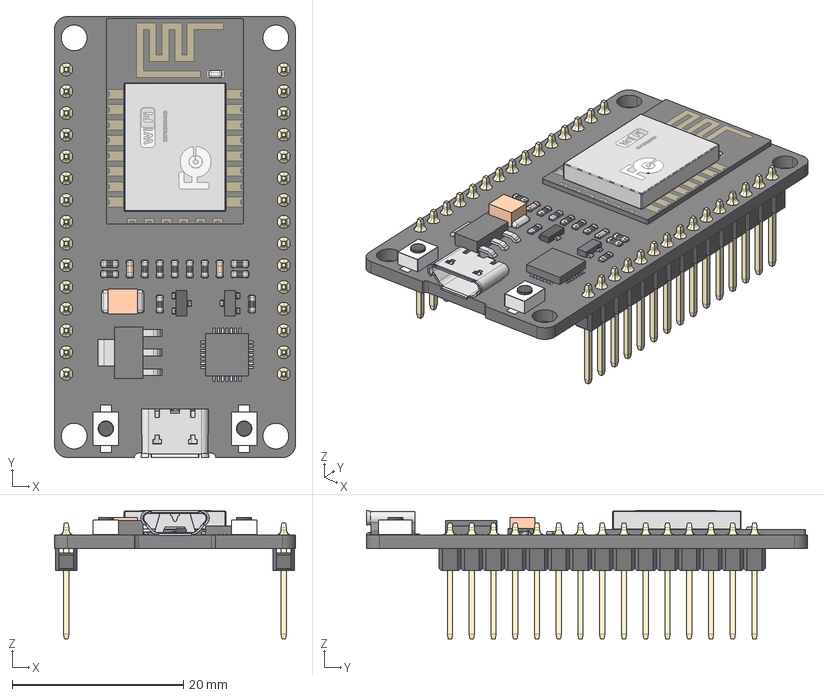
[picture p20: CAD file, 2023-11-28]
src/3D_Design/Resources/esp32_dev_kit_v1_asm.stp
28.1 x 51.5 x 15.0 mm
PCB
PIN x 30
WIFI_CARD_2
RECTANGULARCHIP_2
MICROCHIP_2
TANCHIP_2
TRANSISTOR_3-LEG_2
RESISTOR1_2 x 11
RESISTOR2-32_2 x 2
TRANSISTOR_3-LEG2_2
BUTTONFLASH-13_2 x 2
BUTTONFLASH-14_2 x 2
USB_SOCKET_2

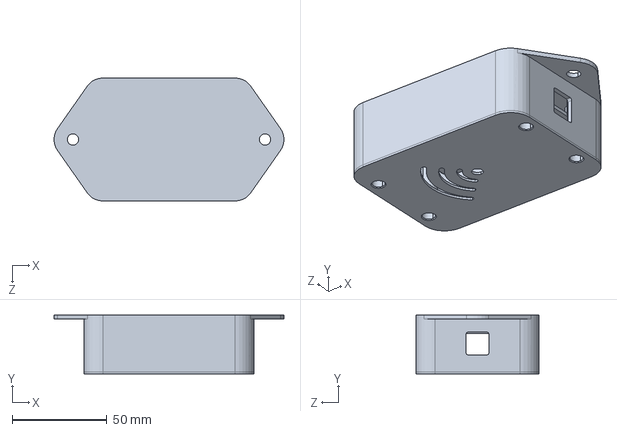
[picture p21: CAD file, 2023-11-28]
src/3D_Design/Misc/Collar_Box_Assembled_I-CowCare_PFA_2022-2023.SLDPRT
121.6 x 31.0 x 65.0 mm

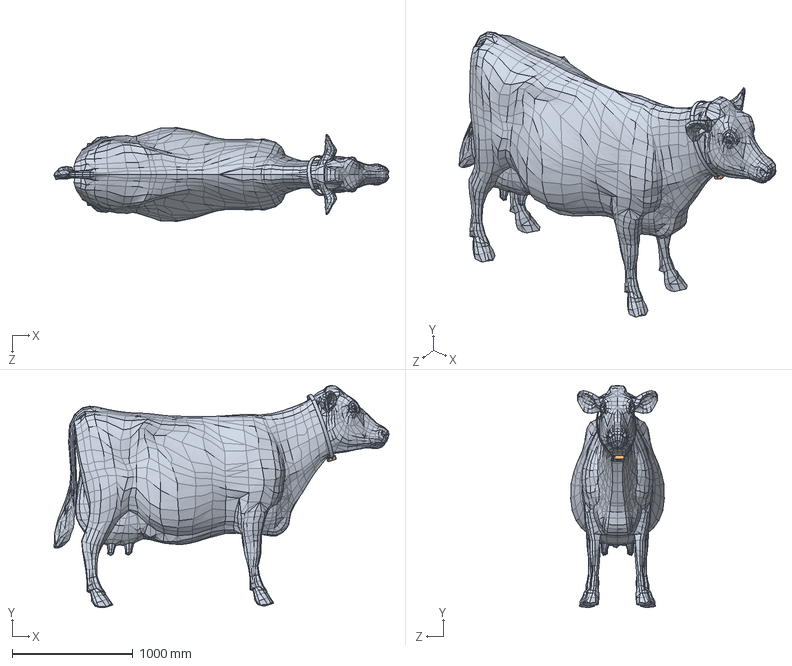
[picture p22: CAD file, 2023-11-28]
src/3D_Design/SOLIDWORKS_Assembly/Assembly_Cow_with_Collar_I-CowCare_PFA_2022-2023.SLDASM
2770.6 x 1838.7 x 774.3 mm
Cow_I-CowCare_PFA_2022-2023
Collar_Box_I-CowCare_PFA_2022-2023
CR123A Battery Holder.step
Boita2_I-CowCare_PFA_2022-2023
Accelerometer_#ADXL377Z_I-CowCare_PFA_2022-2023
Temp_Sensor_I-CowCare_PFA_2022-2023
CR_123A_Battery_I-CowCare_PFA_2022-2023
ESP32_I-CowCare_PFA_2022-2023
Collier_I-CowCare_PFA_2022-2023

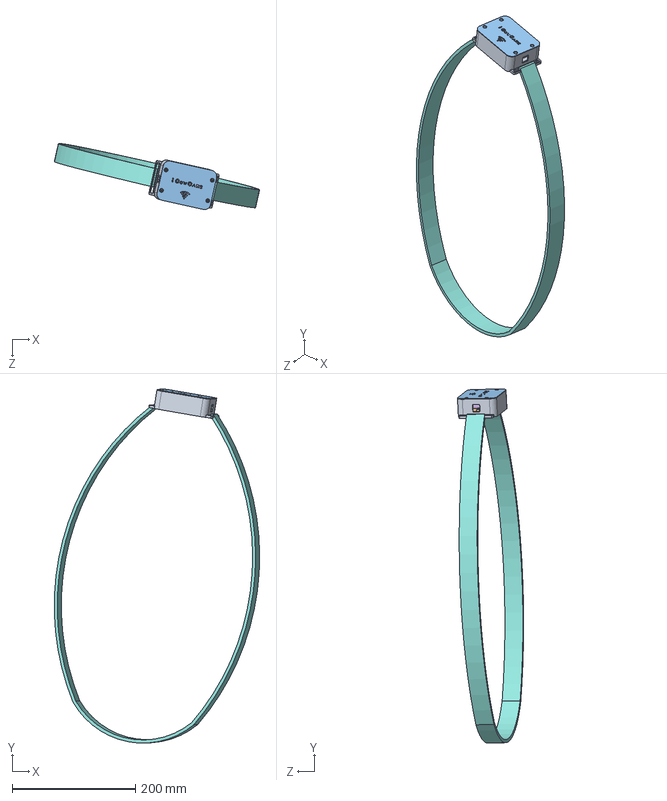
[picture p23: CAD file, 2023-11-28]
src/3D_Design/SOLIDWORKS_Assembly/Assembly_Collar_I-CowCare_PFA_2022-2023.SLDASM
333.3 x 574.6 x 107.4 mm
Collar_Box_Bottom_V2_I-CowCare_PFA_2022-2023
CR123A Battery Holder.step
Collar_Box_Top_I-CowCare_PFA_2022-2023
Accelerometer_ADXL377Z_I-CowCare_PFA_2022-2023
Temp_Sensor_I-CowCare_PFA_2022-2023
CR_123A_Battery_I-CowCare_PFA_2022-2023
ESP32_I-CowCare_PFA_2022-2023
Collier_I-CowCare_PFA_2022-2023

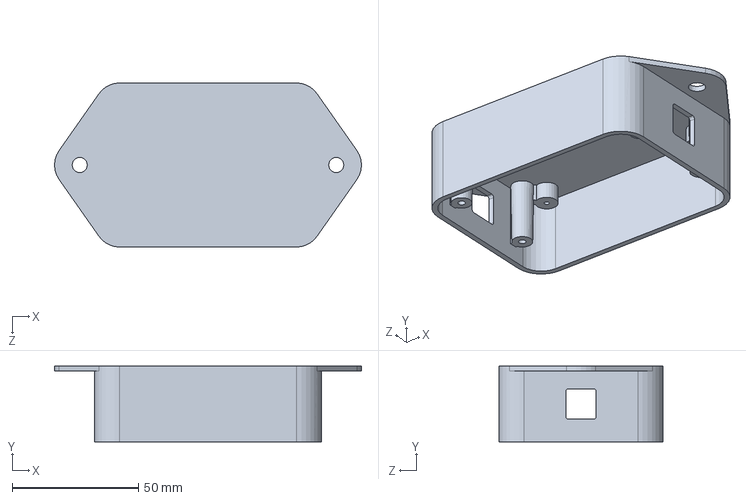
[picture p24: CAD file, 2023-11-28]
src/3D_Design/Misc/Collar_Box_Bottom_V1_I-CowCare_PFA_2022-2023.SLDPRT
121.6 x 30.0 x 65.0 mm

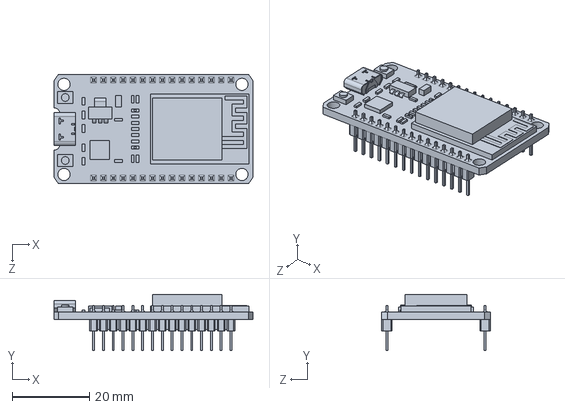
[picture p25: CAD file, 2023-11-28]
src/3D_Design/SOLIDWORKS_Assembly/ESP32_I-CowCare_PFA_2022-2023.SLDPRT
51.5 x 14.5 x 28.3 mm

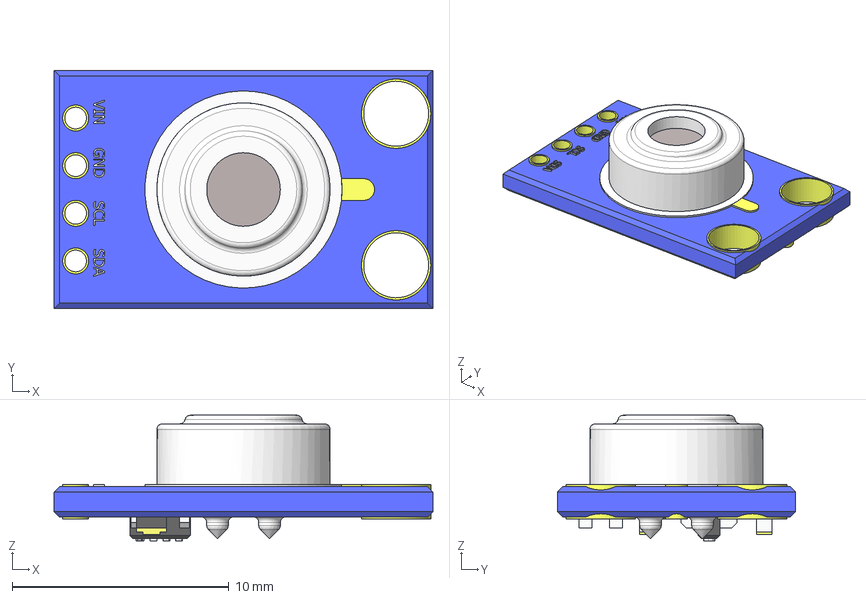
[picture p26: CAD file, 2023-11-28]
src/3D_Design/Resources/Sensor_Temp.stp
17.5 x 11.0 x 5.80 mm

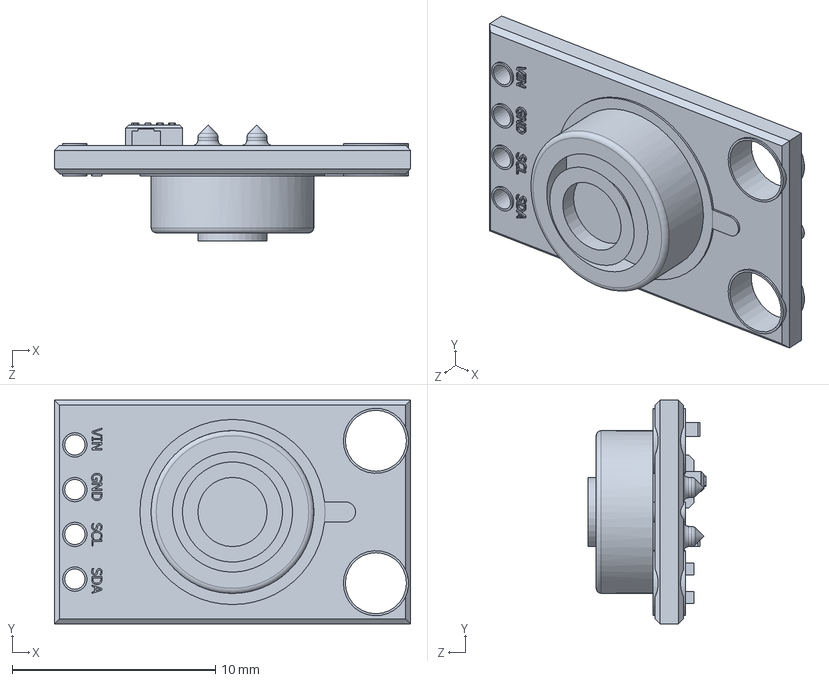
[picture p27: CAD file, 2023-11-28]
src/3D_Design/SOLIDWORKS_Assembly/Temp_Sensor_I-CowCare_PFA_2022-2023.SLDPRT
17.5 x 11.0 x 5.80 mm

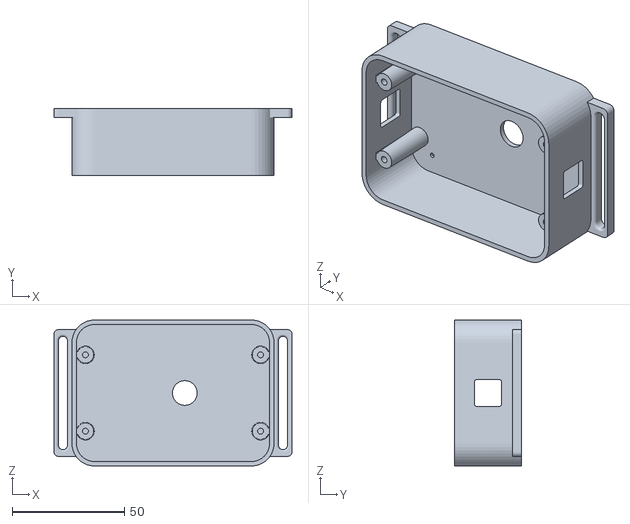
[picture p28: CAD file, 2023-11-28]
src/3D_Design/STL_files/Collar_Box_Bottom_V2_I-CowCare_PFA_2022-2023.STL
106.0 x 30.0 x 65.0

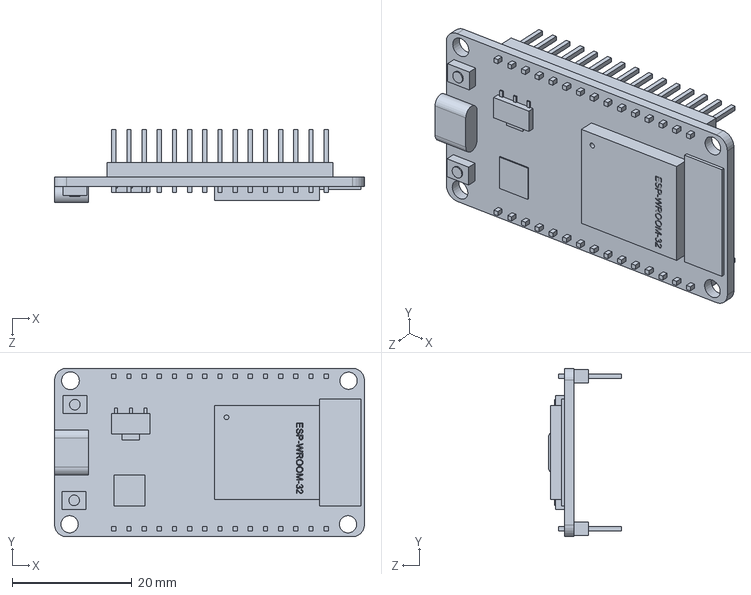
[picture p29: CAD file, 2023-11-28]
src/3D_Design/Misc/ESP32_v2_I-CowCare_PFA_2022-2023.SLDPRT
51.8 x 28.2 x 12.2 mm

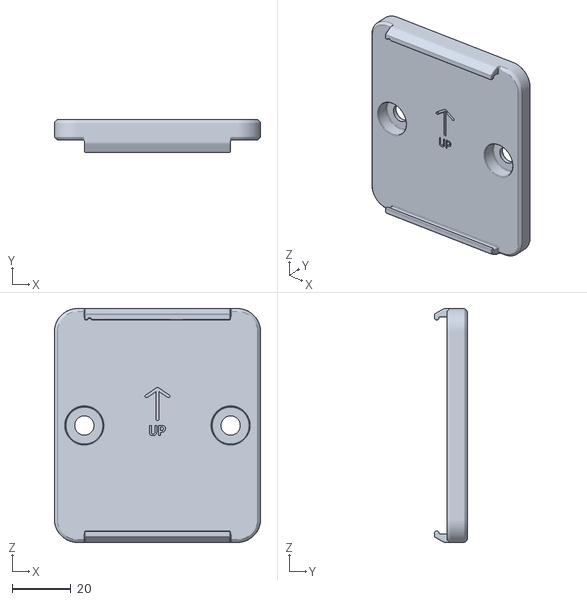
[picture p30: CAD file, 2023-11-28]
src/3D_Design/Resources/D7 - Wall Mount (D7)-1.STL
70.6 x 11.2 x 80.0

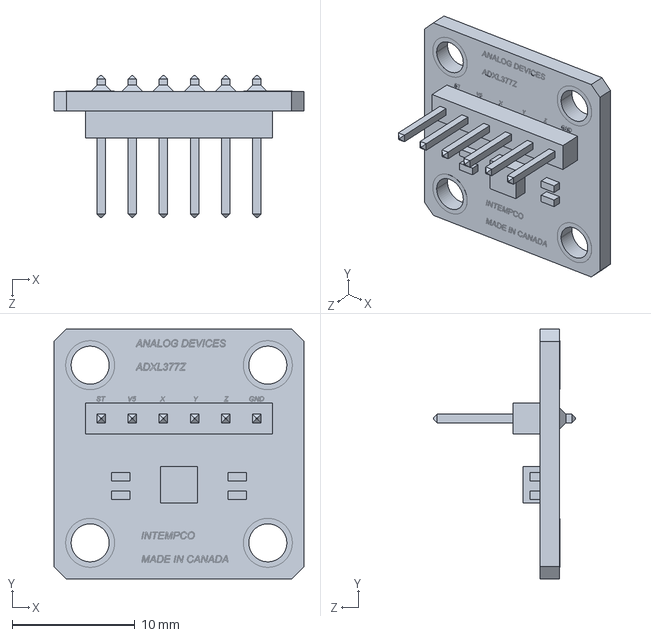
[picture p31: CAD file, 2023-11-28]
src/3D_Design/SOLIDWORKS_Assembly/Акселерометр ADXL377Z.step
20.4 x 20.4 x 11.6 mm

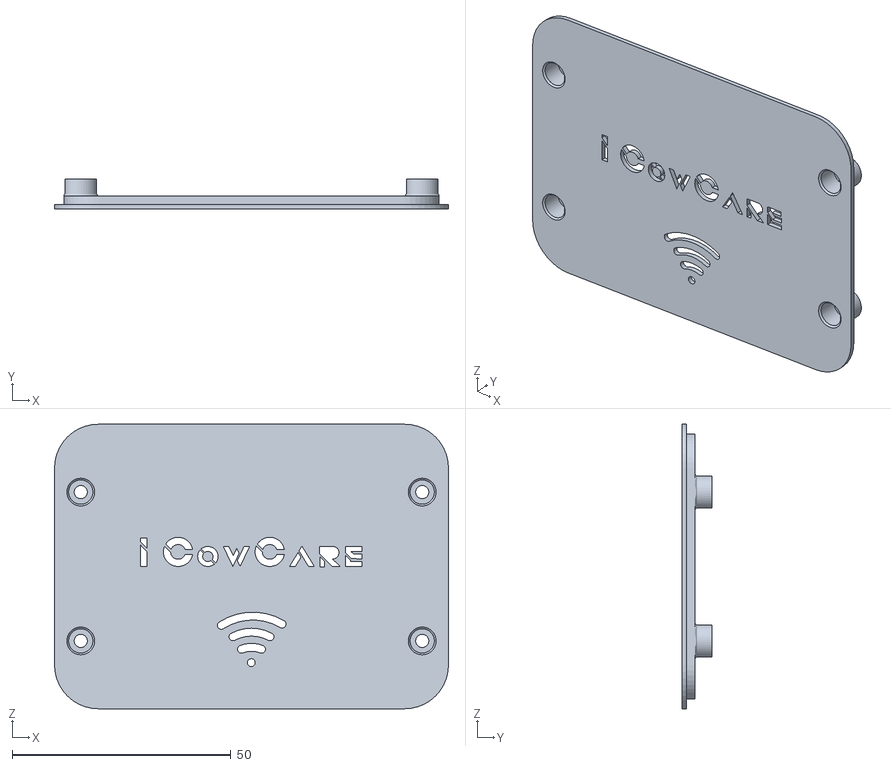
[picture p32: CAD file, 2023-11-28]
src/3D_Design/STL_files/Collar_Box_Top_I-CowCare_PFA_2022-2023.STL
90.0 x 6.80 x 65.0

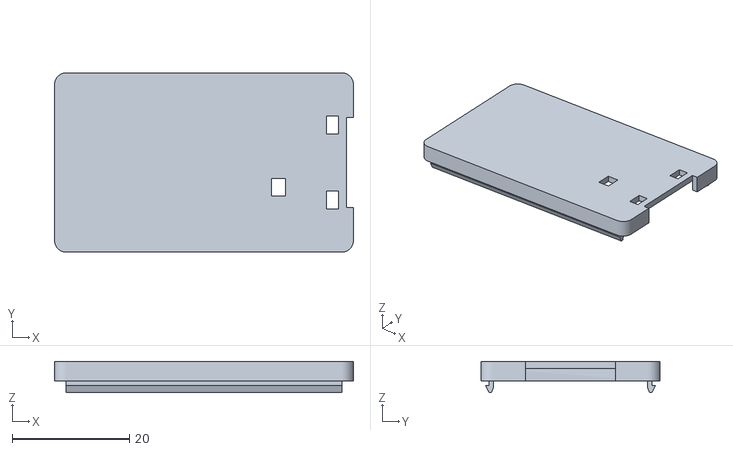
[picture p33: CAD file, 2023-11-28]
src/3D_Design/Resources/PATM-1240_C.STL
51.0 x 30.6 x 5.30

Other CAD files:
src/3D_Design/STL_files/Collar_Box_Bottom_V0_V1_I-CowCare_PFA_2022-2023.stl
src/3D_Design/STL_files/CR_123A_Battery_Holder_I-CowCare_PFA_2022-2023.STL
src/3D_Design/Resources/ESP32 v2.step
src/3D_Design/3D_Printing_Files/ESP8266 BOARD CASE v2.f3d
src/3D_Design/Resources/CR123A Battery Holder.step
src/3D_Design/Resources/D7 - BC (D7)-1.STL
src/3D_Design/Resources/D7 - TC (D7)-1.STL
src/3D_Design/Resources/Holder 3D.STEP
src/3D_Design/Resources/PATM-1240_B.STL
src/3D_Design/Resources/d1001414-00.stp
src/3D_Design/Resources/housing50x70.STEP
src/3D_Design/SOLIDWORKS_Assembly/Accelerometer_ADXL377Z_I-CowCare_PFA_2022-2023.SLDPRT
src/3D_Design/SOLIDWORKS_Assembly/CR123A Battery Holder.step
src/3D_Design/SOLIDWORKS_Assembly/CR_123A_Battery_I-CowCare_PFA_2022-2023.SLDPRT
src/3D_Design/SOLIDWORKS_Assembly/Collar_Box_Bottom_V2_I-CowCare_PFA_2022-2023.SLDPRT
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

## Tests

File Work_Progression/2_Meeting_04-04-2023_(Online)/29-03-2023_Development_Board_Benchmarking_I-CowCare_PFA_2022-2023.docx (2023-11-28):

ESP32 chip energy consumption

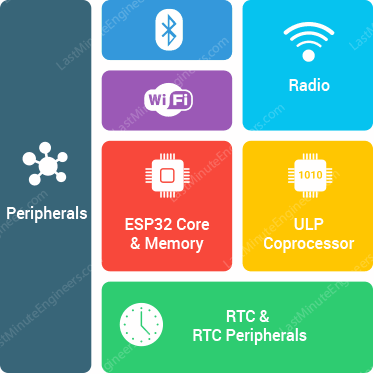
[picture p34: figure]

The ESP32 chip contains a dual-core 32-bit microprocessor along with 448 KB of ROM, 520 KB of SRAM, and 4 MB of flash memory.In addition, the chip contains a WiFi module, a Bluetooth module, a cryptographic accelerator (a co-processor designed specifically to perform cryptographic operations), an RTC module, and a number of peripherals.

## ESP32 Power Modes

- Active Mode
- Modem Sleep Mode
- Light Sleep Mode
- Deep Sleep Mode
- Hibernation Mode

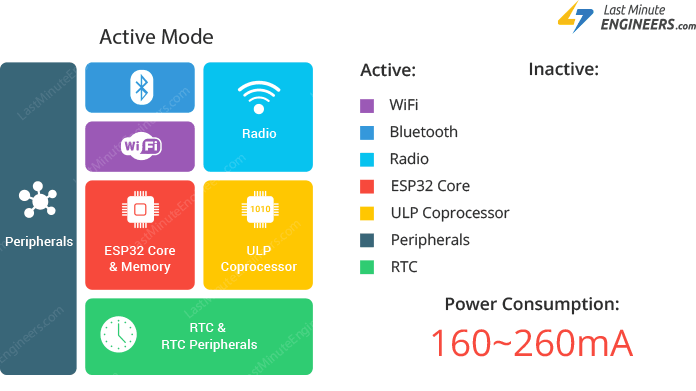
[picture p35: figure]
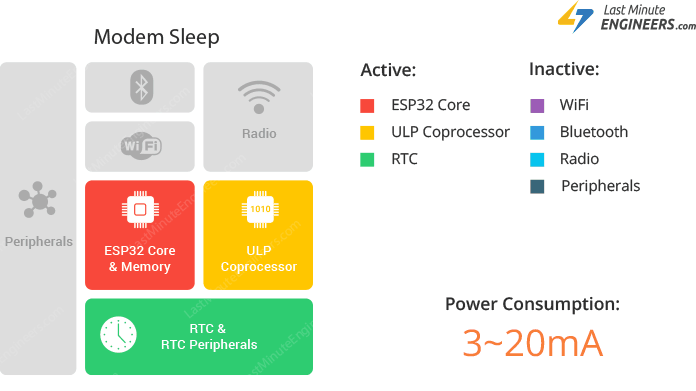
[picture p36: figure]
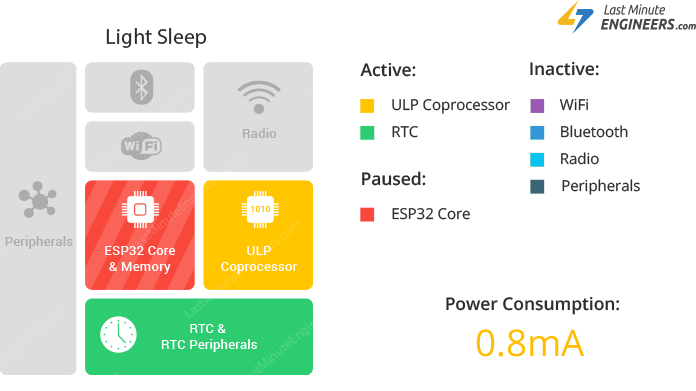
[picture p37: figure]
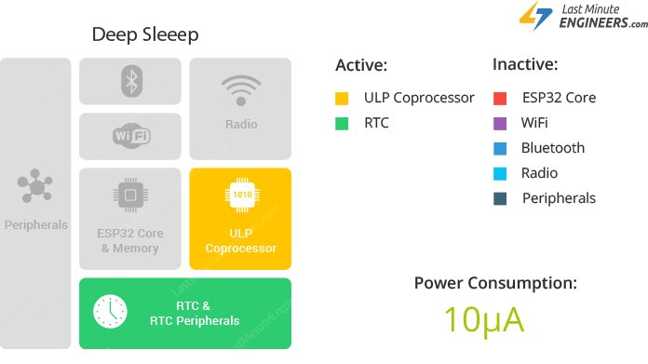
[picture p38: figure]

Name | Pros | Cons | Price | Characteristics | Image

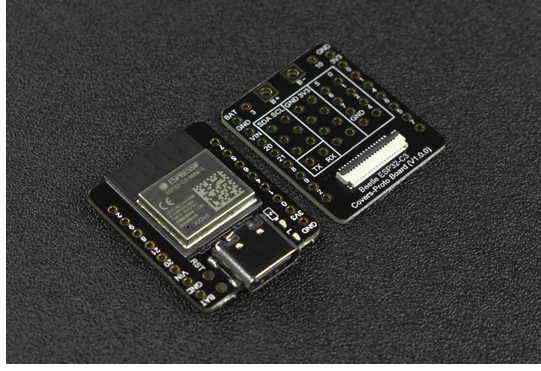
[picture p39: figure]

Beetle ESP32-C3 (https://2betrading.com/cartes-de-developpement/6787-module-beetle-esp32-c3-risc-v-core-development-board.html) | - Low power consumption, making it suitable for battery-powered applications - Dual-core microcontroller running up to 160 MHz - Compact size and low cost | - Single-band Wi-Fi (2.4GHz only) - Limited availability of support and community resources compared to other ESP32-based boards | 52 DT | Operating Voltage: 3.3V Type-C Input Voltage: 5V DC VIN Input Voltage: 5V DC Operating Current: 25mA Maximum Charging Current: 400mA Operating Temperature: -40~105℃ Size: 25 x 20.5mm

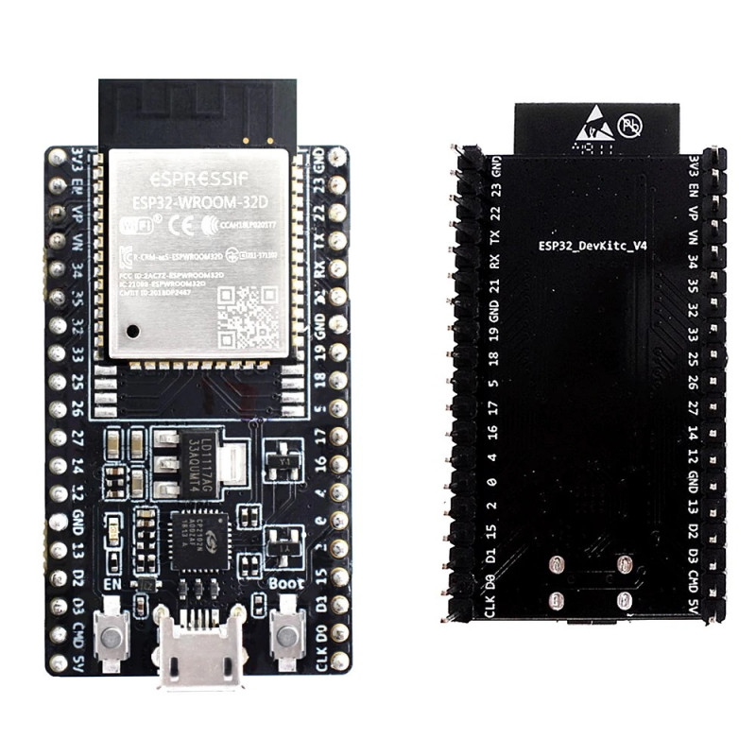
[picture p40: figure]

ESP32-DevKitC V4 (https://2betrading.com/accueil/5370-carte-de-developpement-wifi-bluetooth-iot-esp32-wroom-32d.html) ESP32-WROOM-32D (https://2betrading.com/accueil/5370-carte-de-developpement-wifi-bluetooth-iot-esp32-wroom-32d.html) | - Dual-core microcontroller running up to 240 MHz More memory (520KB SRAM and 4MB flash memory) - Dual-band Wi-Fi (2.4GHz and 5GHz) - Wide availability of support and community resources - Wide range of development boards and modules based on the ESP32-WROOM-32D | - Consume more power compared to the Beetle ESP32-C3 | 42 DT | USB to Serial Port Chip: CP2102-GMR Operating Voltage: DC 5V Operating Current: 80mA Current Supply: 500mA Size 55mm*26mm*13mm Datasheet (https://asset.conrad.com/media10/add/160267/c1/-/gl/002490159DS00/datasheet-2490159-espressif-pcb-design-board-esp32-devkitc-vie.pdf)

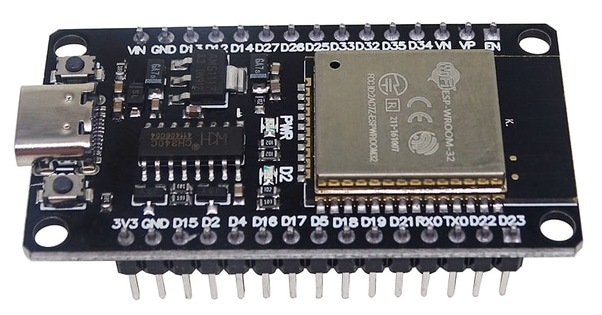
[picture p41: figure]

ESP32 CH340C CP2102 (https://2betrading.com/accueil/6856-nouvelle-version-carte-esp32-esp-32-cp2102-wifi-bluetooth-usb-type-c.html) | - Dual-core microcontroller running up to 240 MHz - More memory options (520KB SRAM and 4MB flash memory) - Dual-band Wi-Fi (2.4GHz and 5GHz) | - Limited availability of support and community resources compared to other ESP32-based boards - May consume more power compared to the Beetle ESP32-C3 - May require additional components, such as voltage regulator and crystal oscillator, to operate | 39 DT

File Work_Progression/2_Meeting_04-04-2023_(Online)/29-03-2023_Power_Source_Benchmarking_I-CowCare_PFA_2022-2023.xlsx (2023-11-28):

 | V | mAh | Self discharge / Monat | Pro | Con | Price / Battery in € | Price / Ah in € | Price / Ah at min. 2.5 V in €
Powerbank | 5 | 20100 | ca. 4% | easy installation | high energy waste due to multiple level shifting of the voltage (internal 3.7 V -> 5V -> 3.3 V in ESP), switches off, large form factor | 35.99 | 1.79 | 1.79
Batteries (Primary-Cells)
Alkaline AA | 2023-05-01 | 2000 | ca. 6% | cheap | early onset of voltage drop, approx. 50-70 % of the energy remains unused, current peaks of the ESP too large with WiFi, not rechargeable | 0.24 | 0.12 | 0.24
Lithium CR123 | 3 | 1600 | 1-2% | only well working variant for non-rechargeable batteries | not rechargeable | 2.19 | 1.53 | 1.53
Lithium CR2 | 3 | 880 | 1-2% | like CR123 | like CR123, but less capacity | 2.19 | 2.48 | 2.48
Accumulators (Secondary Cells)
NiMH AA | 2023-02-01 | 2000 | ca. 25% (!) | cheap | high self-discharge, memory effect, too close to the voltage limit | 1.60 | 0.80 | 2.40
LSD-NiMH AA | 2023-02-01 | 2000 | 1-3% | no memory effect, low self-discharge | too close to the voltage limit, expensive | 4.98 | 2.49 | 7.47
Lithium AA | 2023-05-01 | 2200 | ca. 4% | kein Memory-Effekt, geringe Selbstentladung, viel Kapazität | more expensive | 6.25 | 2.84 | 5.68
LiFePo AA | 2023-02-03 | 600 | ca. 3-5% | no memory effect, low self-discharge, much capacity | most expensive, low capacity | 4.60 | 7.66 | 7.66
LiFePo ANR26650M1B | 2023-02-03 | 2500 | ca. 3-5% | no memory effect, low self-discharge, much capacity | expensive, large form factor | 10.90 | 4.36 | 4.36

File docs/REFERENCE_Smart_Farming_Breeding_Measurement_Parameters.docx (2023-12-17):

Smart Farming

Introduction

Selon les prévisions de la FAO, d’ici à 2050, la population mondiale aura augmenté d’un tiers, et la hausse la plus forte sera enregistrée dans les pays en développement. Pour nourrir la population mondiale croissante et offrir la base nécessaire à la croissance économique et à la réduction de la pauvreté, l’agriculture doit véritablement se transformer. A titre d’exemple, les animaux d’élevage nécessitent une surveillance fréquente concernant leur santé et leurs habitudes alimentaires. L’élevage va devoir opérer une transition vers des systèmes qui soient plus productifs, qui utilisent les intrants de façon plus efficiente, qui soient moins variables et plus stables dans leur production, et qui soient plus résilients face aux risques, aux chocs et à la variabilité du climat à long terme. Toutefois, les troupeaux s'agrandissent mais la santé, les performances et le bien-être des animaux d'élevage nécessitent un suivi continu et de plus en plus précis (Veissier et al., 2019) . Parallèlement, les éleveurs aspirent aussi à une autre organisation du travail.

C'est pour répondre à ces exigences qu'est née cette idée de projet basée sur utilisation combinée de biocapteurs et de technologies de l'information et de la communication pour améliorer la conduite des troupeaux, avec comme buts l'efficience de l'élevage et la simplification du travail de l'éleveur. En effet, plusieurs systèmes d’EdP ont été proposés afin de détecter précocement les troubles de santé, ceux-ci ayant des répercussions économiques importantes (Steensels et al., 2016 ; Steensels et al., 2017).

Chez les bovins, les dispositifs d’élevage de précision - initialement développés pour l’aide à la détection des chaleurs (Saint-Dizier et Chastant-Maillard, 2018), sont basés sur la détection des activités des animaux: c’est parce qu’un animal est détecté hyperactif que l’on détectera un œstrus ou au contraire parce qu’il est hypoactif que l’on suspectera un problème de santé. Grâce à des accéléromètres, il est possible de savoir si un animal marche, s’il est debout ou couché (bovins : Benaissa et al., 2017 ; ovins : Barwick et al., 2018 ; volailles : Casey-Trott et Widowski, 2018).

1- Les paramètres à mesurer
  1-1 Température rectale

## La température normale pour :

## Vaches : La température corporelle d’une vache adulte se situe normalement entre 38,0 et 39,0°C.

## Génisses : La température corporelle d’une génisse se situe normalement entre 38.0 et 39.5°C.

## Veaux : La température corporelle d’un veau se situe normalement entre 38,5 et 39,5°C.

NB : La température corporelle peut être plus élevée (fièvre, hyperthermie) ou plus basse (température basse, hypothermie). La température de la vache doit se situer entre 38 et 39 °C. Des oreilles froides indiquent une fièvre du lait ou des problèmes de circulation sanguine.

Les premiers signes: Une température légèrement plus élevée peut être le premier signe d’une affection aiguë, bien avant d’autres symptômes tels qu’une baisse de la production laitière ou la perte d’appétit. Si un animal est traité à ce stade précoce, les chances de guérison sont plus élevées que si l’on n’intervient qu’une fois la maladie déclarée. Si la température corporelle dépasse les 39,5°C, l’animal doit rapidement être examiné et traité par un vétérinaire.

Petit rappel: lorsque les températures extérieures prennent l’ascenseur, la température corporelle des bovins peut légèrement augmenter (jusqu’à 39.5°C env.) sans pour autant être inquiétante.

Si la température corporelle d’un animal augmente rapidement lors de températures extérieures

  1-2 Rythme respiratoire

Une respiration normale se situe entre 10 et 30 pulsations par minute pour une vache. Une respiration plus rapide indique un stress lié à la chaleur ou une douleur ou de la fièvre. Les mouvements respiratoires, qui passent de 30 mouvements/minute en temps normal, à 50 mouvements/minute lorsque la vache est stressée.

  1-3 Battements cardiaques

La fréquence cardiaque normale est de 60 à 80 bpm chez un bovin adulte. Le pouls se prend par palpation-pression au niveau de l’artère faciale (au bord inférieur de l’os maxillaire) ou de l’artère coccygienne (face intérieure de la queue). Les battements de cœur doivent être réguliers (on peut apprécier un trouble du rythme cardiaque en posant une main sur la région du cœur).

  1-4 Détection des chaleurs
- Prérequis: Cycle d’ovulation d’une vache

Tant qu’une vache ou une génisse n’est pas gestante, celle-ci suit un cycle d’ovulation de 21 jours. La durée du cycle d’ovulation peut varier mais généralement elle se situe entre 17 et 24 jours. Le cycle d’ovulation d’une génisse est généralement un peu plus court que celui d’une vache. Ce cycle se répètera jusqu’à ce que la vache soit gestante. Après le vêlage, les vaches entreront dans une période de 20 à 30 jours pendant laquelle il n’y aura pas de cycles d’ovulation. Cette période peut être plus longue chez les vaches hautes productrices (40-60j), dans l’incapacité de prendre suffisamment d’énergie pour couvrir entièrement la production de lait. La vache se protègera elle-même et attendra le retour des cycles.

- Augmentation de l’activité

Une autre manière de repérer les vaches en chaleur consiste à mesurer leur activité. Les vaches peuvent être jusqu’à huit fois plus actives lorsqu’elles sont en chaleur. Cette activité peut être mesurée automatiquement à l’aide de détecteurs d’activité fixés à la patte ou au cou. En comparant le niveau d’activité avec la dernière chaleur observée, la production réelle et la consommation, on peut obtenir une indication de chaleur fiable. L’activité mètre vous permettra d’effectuer des gains de temps significatifs et d’améliorer les intervalles entre les vêlages grâce à une meilleure détection des chaleurs.

2- Outils numériques de surveillance

Il existe des outils numériques qui permettent de vérifier que chaque indicateur de santé est bien respecté (tableau 1):

Tableau 1 : Exemples d’outils numériques de surveillance utilisés en élevage

Indicateur | Outils numériques
Absence de faim, de soif et de malnutrition | Capteurs de nutrition : caméras 3D infrarouge, pHmètre pour mesurer le pH du rumen, accéléromètre pour suivre la rumination, pesoirs, bascules pour quantifier la quantité d’aliments ingérés.
Absence de peur et de détresse | Contrôler le bon étourdissement des porcs et bovins à l’abattoir avec le projet CET automatique (https://neotec-vision.com/) (NeoTec Vision, IDELE, IFIP, INAPORC, INTERBEV) : solution d’imagerie pour détecter l’absence de mouvement de l’œil et de réflexe cornéen.
Absence de stress physique et/ou thermique | Objets connectés et capteurs pour un suivi des comportements des vaches laitières en temps réel. Par exemple, FarmLife est une application web et mobile pour le suivi des animaux (Medria, plateforme ITK). Medria (https://www.medria.fr/) propose notamment un accéléromètre (collier) qui est un indicateur de confort. Il mesure les temps de postures « debout » et « couché », détecte la suractivité, les boîteries et peut envoyer des alertes à l’éleveur en cas de comportement déviant d’un animal.
Absence de douleurs, lésions et maladie | Accéléromètre : en cas d’inflammation, moins de mouvements, perte de motivation alimentaire. Suivi des températures de l’animal en continu (ex : thermobolus)

Liberté d’expression d’un comportement normal de son espèce

Système de localisation, détecteur de comportement positif. Projet CLOCHèTE (http://idele.fr/reseaux-et-partenariats/otop3d/publication/idelesolr/recommends/clochete-des-capteurs-embarques-au-service-des-elevages-pastoraux.html) : colliers connectés permettant aux éleveurs de géolocaliser rapidement leurs animaux, fournissant des alertes en cas de comportements inhabituels (cas d’attaques) grâce à un accéléromètre. Cattlechain (https://cattlechain.eu/): projet de suivi de l’accès au pâturage des bovins lait et viande jusqu’au consommateur par blockchain.

3- Retombés socio-économiques

Un éleveur laitier attend beaucoup de ses vaches. Elles doivent produire beaucoup de lait, donner naissance à un veau une fois par an et avoir un minimum de problèmes de santé. Cependant, vous pouvez comparer les vaches aux sportifs de haut niveau. Même les meilleurs compétiteurs ne peuvent réaliser de bonnes performances sans de bonnes conditions de vie. Les vaches ne pourront pas répondre aux attentes de l’éleveur si elles ne vivent pas dans des conditions optimales. L’éleveur doit créer un environnement dans lequel les vaches se sentent bien pour qu’elles répondent à ses attentes. Avec des vaches en bonne santé et calmes, les productions seront certainement au-delà des attentes de l’éleveur qui profitera d’un élevage plus rentable.

Références

1- Barwick J., Lamb D.W., Dobos R., Welch M., Trotter M., 2018. Categorising sheep activity using a tri-axial accelerometer. Comput. Electron. Agricult., 145, 289-297.
2- Benaissa S., Tuyttens F.A.M., Plets D., De Pessemier T., Trogh J., Tanghe E., Martens L., Vandaele L., Van Nuffel A., Joseph W., Sonck B., 2017. Behaviours recognition using neck-mounted accelerometers in dairy barns. In: EC-PLF. Berckmans D., Keita A. (Eds), Nantes, France, 69-76.
3- Casey-Trott T., Widowski T., 2018. Validation of an accelerometer to quantify inactivity in laying hens with or without keel-bone fractures. Anim. Welfare, 27, 103-114.
4- Isabelle Veissier, (https://productions-animales.org/search/authors/view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)Florence Kling-Eveillard, (https://productions-animales.org/search/authors/view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)Marie-Madeleine Mialon, (https://productions-animales.org/search/authors/view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)Mathieu Silberberg, (https://productions-animales.org/search/authors/view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)Alice De Boyer Des Roches, (https://productions-animales.org/search/authors/view?givenName=Alice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)Claudia Terlouw, (https://productions-animales.org/search/authors/view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)Dorothée Ledoux, (https://productions-animales.org/search/authors/view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)Bruno Meunier, (https://productions-animales.org/search/authors/view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)Nathalie Hostiou (https://productions-animales.org/search/authors/view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), 2019 Élevage de précision et bien-être en élevage : la révolution numérique de l’agriculture permettra-t-elle de prendre en compte les besoins des animaux et des éleveurs ? Vol. 32 No 2 (2019): Volume 32 Numéro 2 : Numéro spécial. De grands défis et des solutions pour l'élevage 281-290 (https://productions-animales.org/issue/view/284)
5- Saint-Dizier M., Chastant-Maillard S., 2018. Potential of connected devices to optimize cattle reproduction. Therio., 112, 53-62.
6- Steensels M., Antler A., Bahr C., Berckmans D., Maltz E., Halachmi I., 2016. A decision-tree model to detect post-calving diseases based on rumination, activity, milk yield, BW and voluntary visits to the milking robot. Animal, 10, 1493-1500.
7- Steensels M., Maltz E., Bahr C., Berckmans D., Antler A., Halachmi I., 2017. Towards practical application of sensors for monitoring animal health: the effect of post-calving health problems on rumination duration, activity and milk yield. J. Dairy Res., 84, 132-138.

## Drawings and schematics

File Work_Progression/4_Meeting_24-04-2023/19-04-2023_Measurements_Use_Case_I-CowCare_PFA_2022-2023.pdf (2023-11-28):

# ICowCare

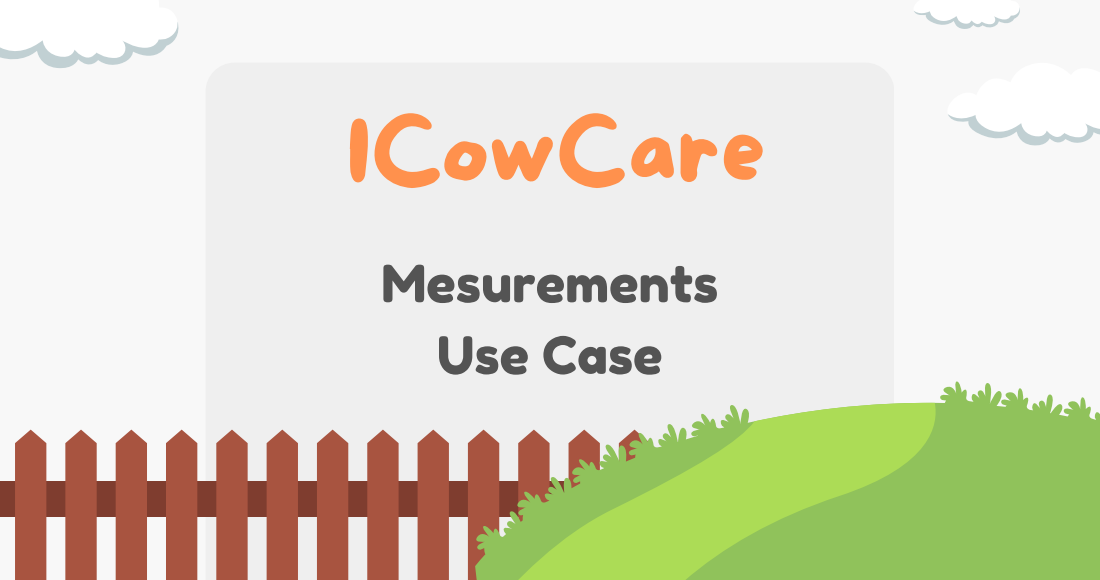
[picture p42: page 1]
Mesurements Use Case

# Flow Diagram

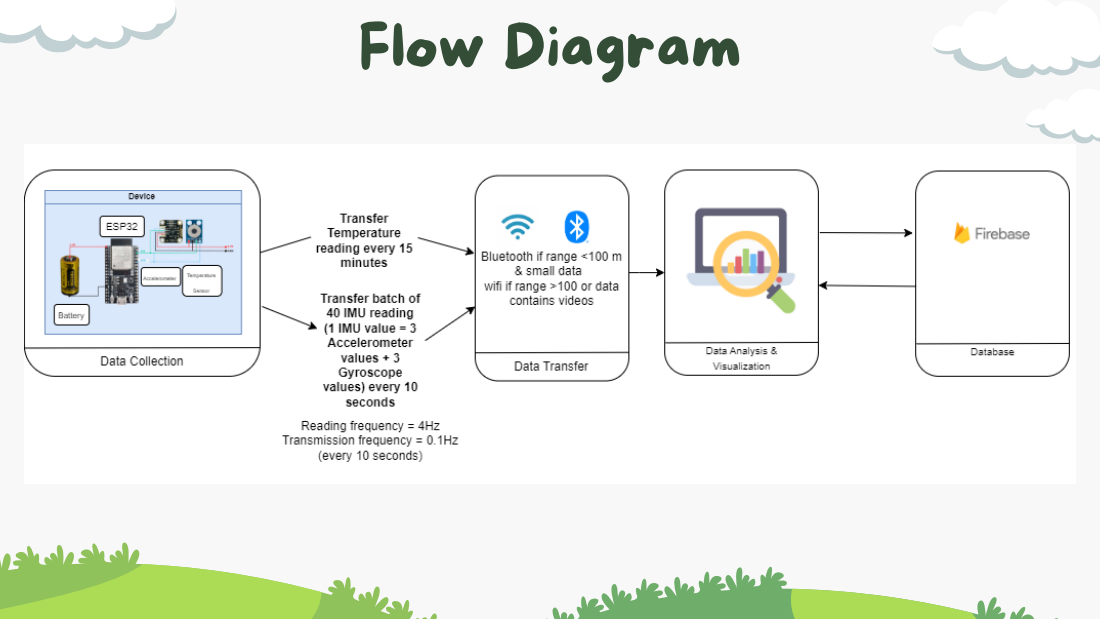
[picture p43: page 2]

# Flow Diagram

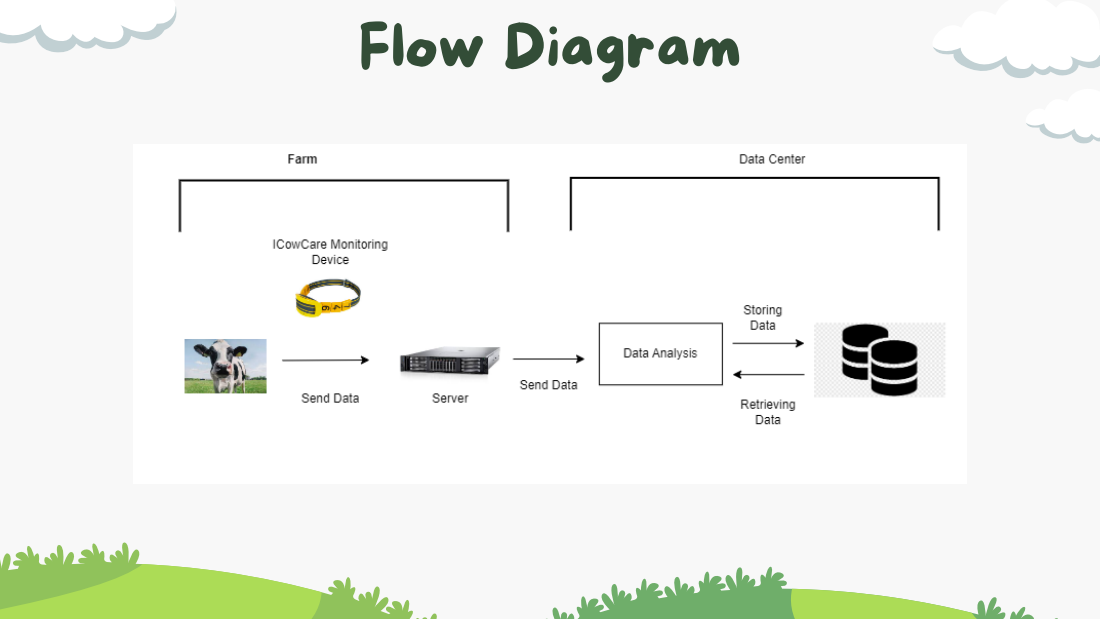
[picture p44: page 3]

# Battery Life Estimation

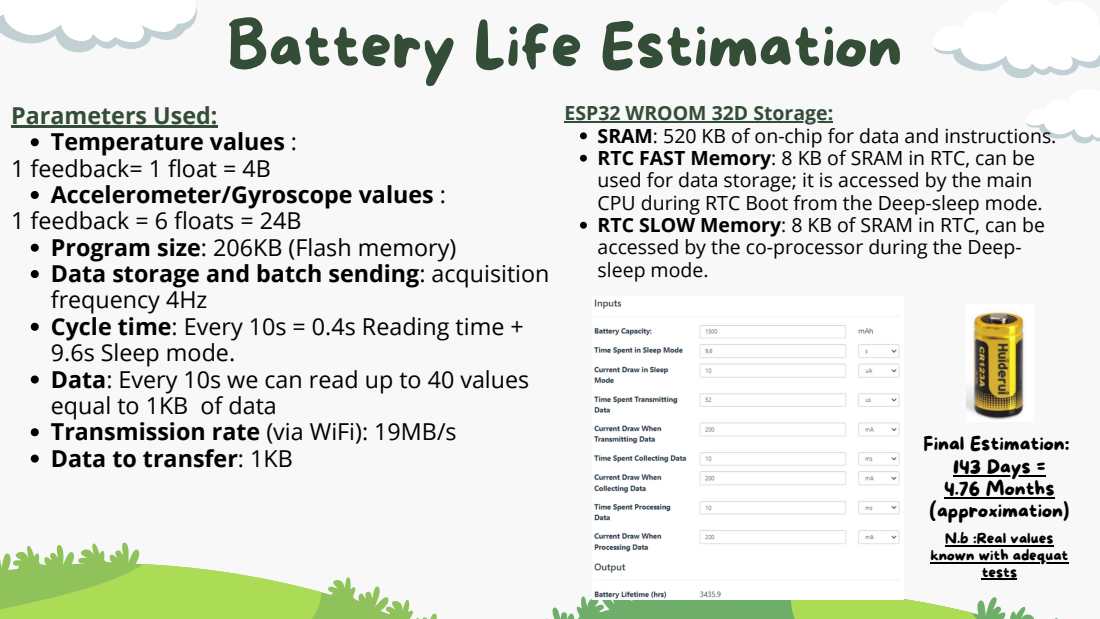
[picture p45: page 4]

Parameters Used:
Temperature values :
1 feedback= 1 float = 4B
Accelerometer/Gyroscope values :
1 feedback = 6 floats = 24B
Program size: 206KB (Flash memory)
Data storage and batch sending: acquisition
frequency 4Hz
Cycle time: Every 10s = 0.4s Reading time +
9.6s Sleep mode.
Data: Every 10s we can read up to 40 values
equal to 1KB of data
Transmission rate (via WiFi): 19MB/s
Data to transfer: 1KB

ESP32 WROOM 32D Storage: (https://asset.conrad.com/media10/add/160267/c1/-/gl/002490159DS00/datasheet-2490159-espressif-pcb-design-board-esp32-devkitc-vie.pdf)
SRAM: 520 KB of on-chip for data and instructions.
RTC FAST Memory: 8 KB of SRAM in RTC, can be
used for data storage; it is accessed by the main
CPU during RTC Boot from the Deep-sleep mode.
RTC SLOW Memory: 8 KB of SRAM in RTC, can be
accessed by the co-processor during the Deep-
sleep mode.

Final Estimation:
143 Days =
4.76 Months
(approximation)
N.b :Real values
known with adequat
tests

# Code Simulation

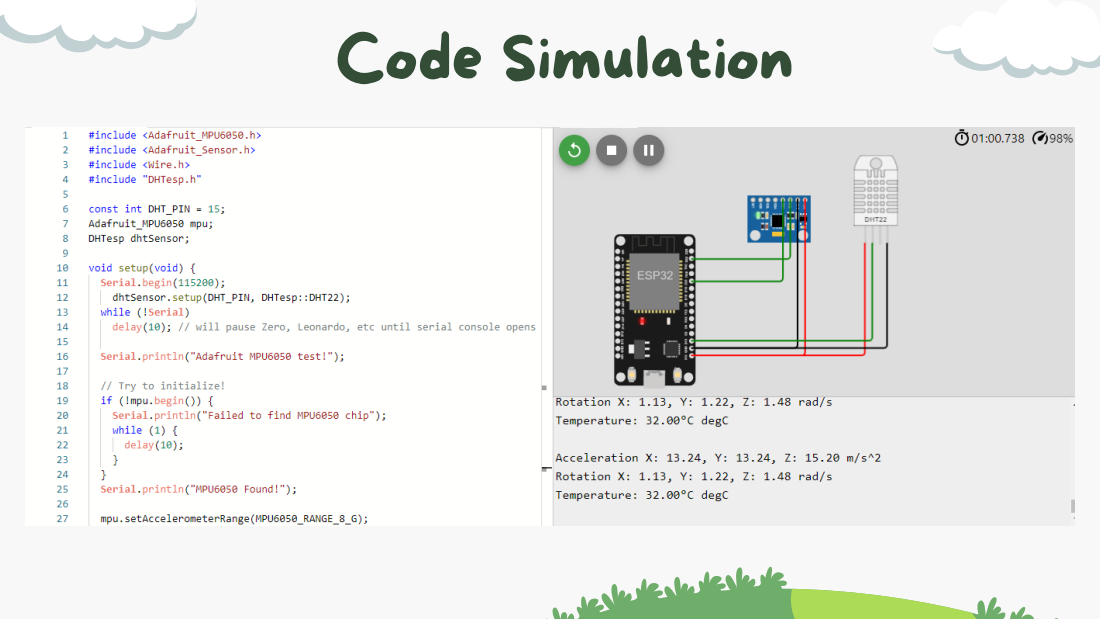
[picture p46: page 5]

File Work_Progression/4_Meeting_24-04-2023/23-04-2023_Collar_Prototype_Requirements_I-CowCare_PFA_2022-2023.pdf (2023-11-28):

## PROTOTYPE REQUIREMENTS

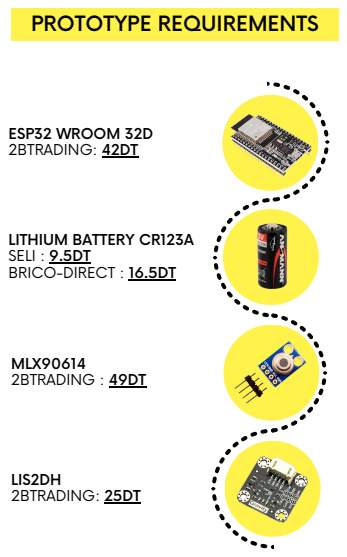
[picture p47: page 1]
ESP32 WROOM 32D 2BTRADING: 42DT; LITHIUM BATTERY CR123A SELI : 9.5DT BRICO-DIRECT : 16.5DT; MLX90614 2BTRADING : 49DT; LIS2DH 2BTRADING: 25DT

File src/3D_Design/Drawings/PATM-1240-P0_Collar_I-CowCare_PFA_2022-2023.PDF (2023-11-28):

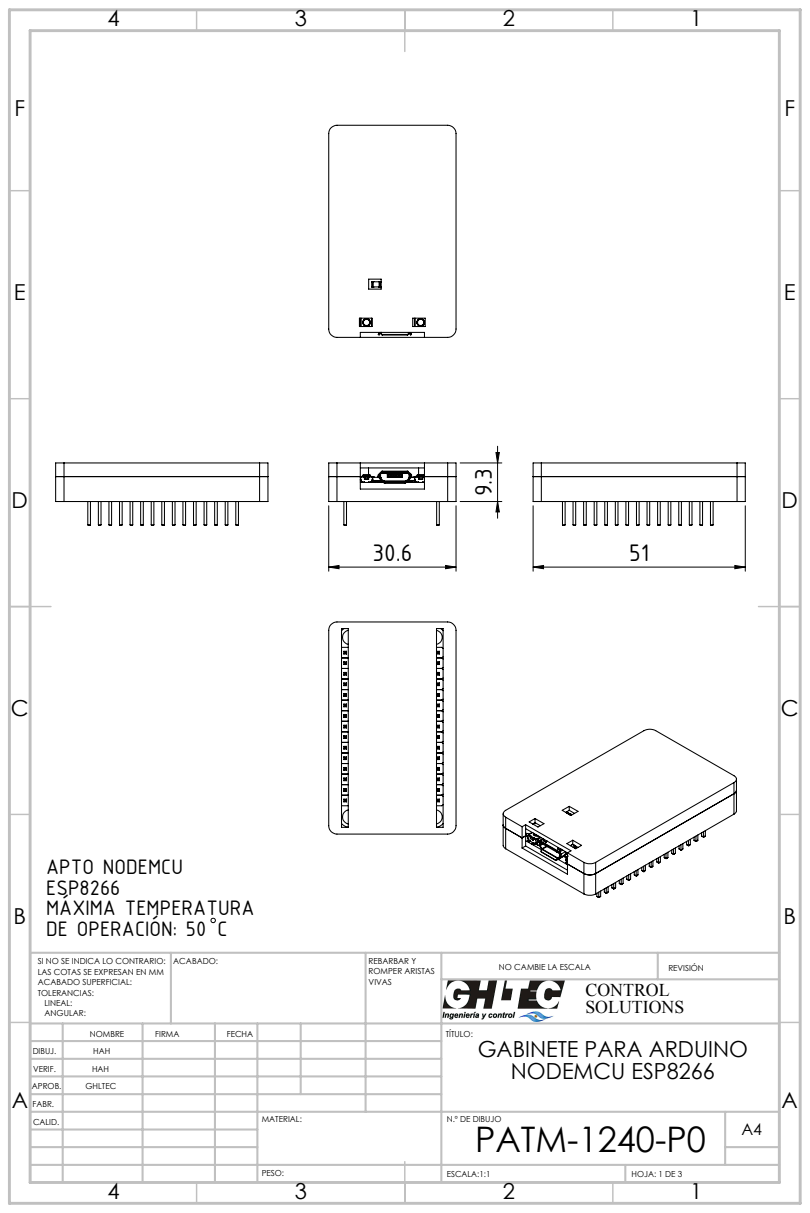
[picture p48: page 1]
ACABADO:; REBARBAR Y; ROMPER ARISTAS; NO CAMBIE LA ESCALA; REVISIÓN; ESCALA:1:1; HOJA: 1 DE 3

APTO NODEMCU
ESP8266 MÁXIMA TEMPERATURA DE OPERACIÓN: 50 C

SI NO SE INDICA LO CONTRARIO:
LAS COTAS SE EXPRESAN EN MM
ACABADO SUPERFICIAL:
TOLERANCIAS:
LINEAL:
ANGULAR:

NOMBRE | FIRMA | FECHA | | | | TÍTULO: GABINETE PARA ARDUINO NODEMCU ESP8266

DIBUJ. | HAH
VERIF. | HAH
APROB. | GHLTEC
FABR.
CALID. | | | | MATERIAL: | N.º DE DIBUJO PATM-1240-P0 | A4

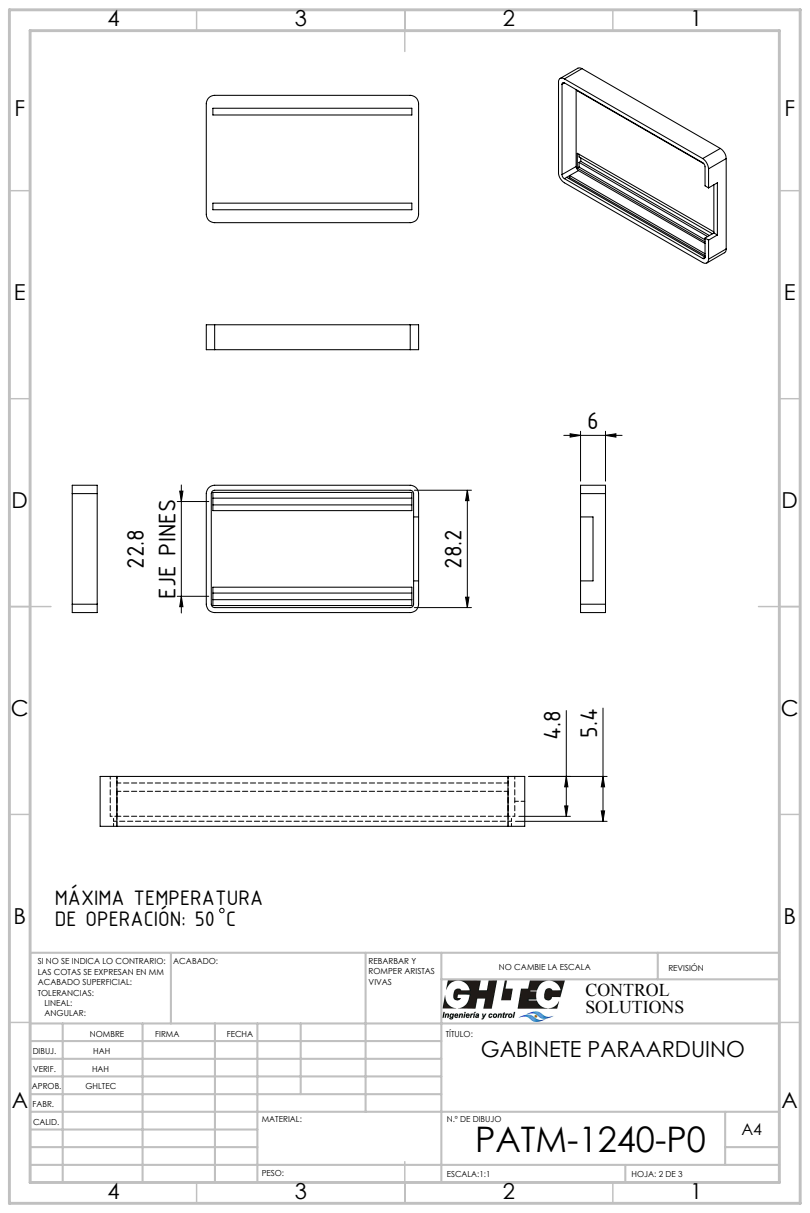
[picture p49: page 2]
EJE PINES; ACABADO:; REBARBAR Y; ROMPER ARISTAS; NO CAMBIE LA ESCALA; REVISIÓN

MÁXIMA TEMPERATURA DE OPERACIÓN: 50 C

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

NOMBRE | FIRMA | FECHA | TÍTULO: GABINETE PARAARDUINO

DIBUJ. | HAH
VERIF. | HAH
APROB. | GHLTEC
FABR.

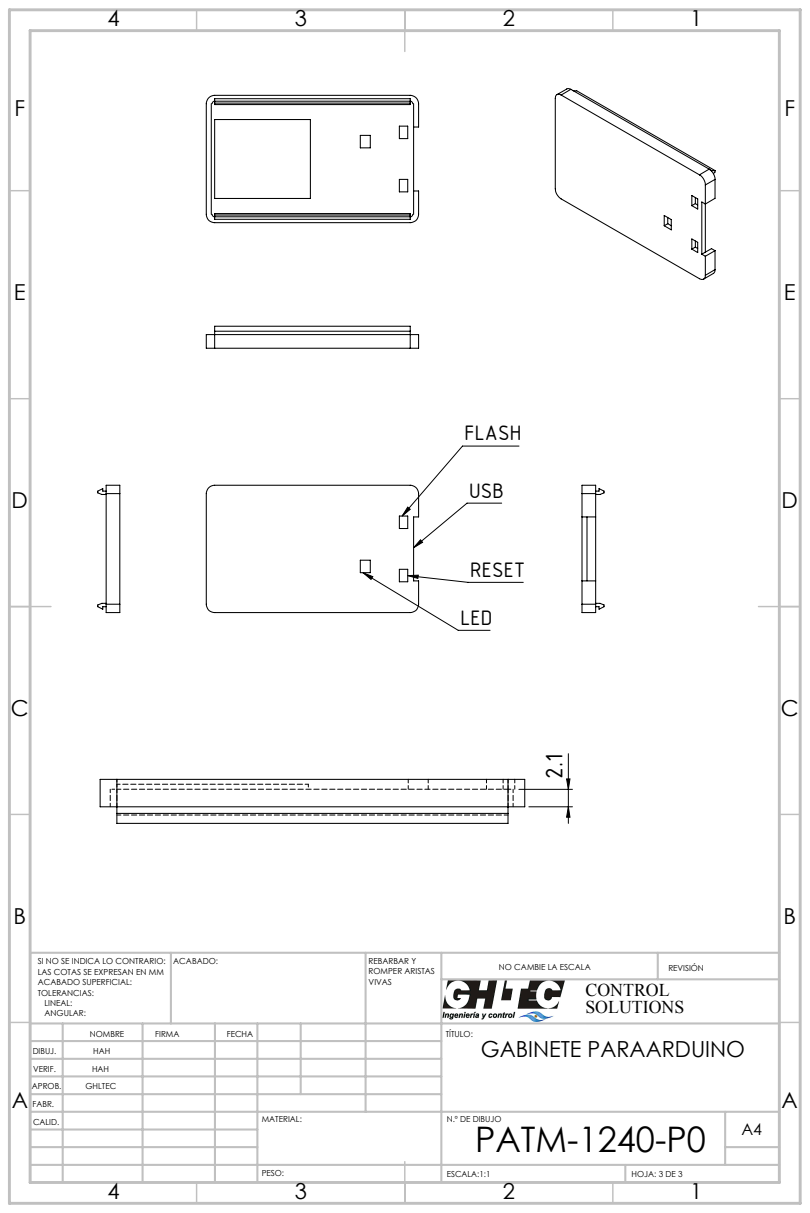
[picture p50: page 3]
ACABADO:; REBARBAR Y; ROMPER ARISTAS; NO CAMBIE LA ESCALA; REVISIÓN

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

NOMBRE | FIRMA | FECHA | TÍTULO: GABINETE PARAARDUINO

DIBUJ. | HAH
VERIF. | HAH
APROB. | GHLTEC
FABR.

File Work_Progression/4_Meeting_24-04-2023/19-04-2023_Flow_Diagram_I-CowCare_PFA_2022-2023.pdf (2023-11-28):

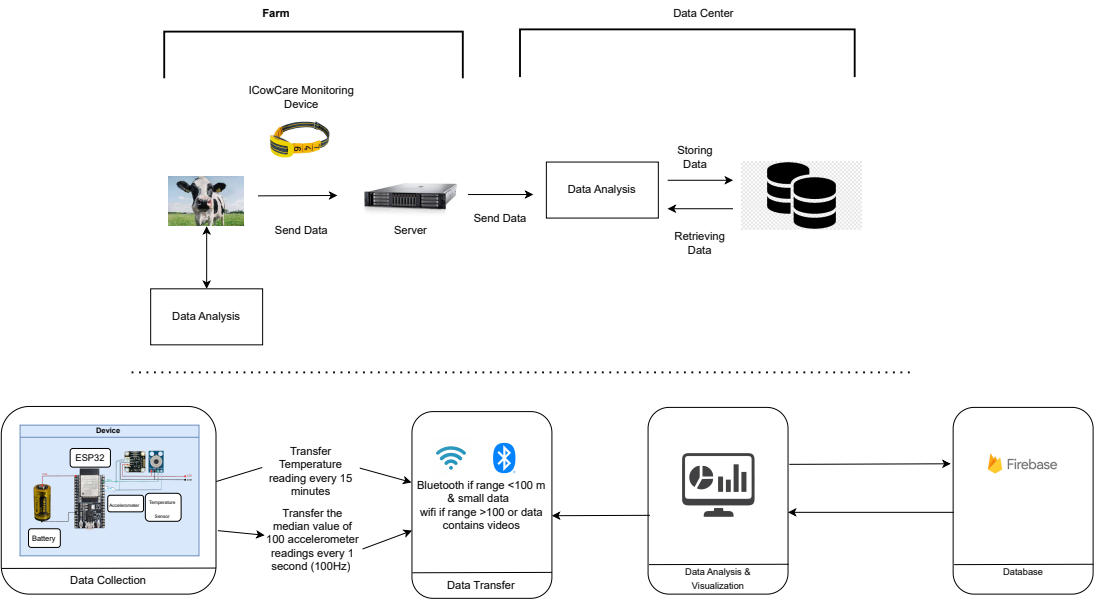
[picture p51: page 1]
Farm; Data Analysis; Data Collection; ESP32; Accelerometer; Temperature; Sensor; Battery; Device; Data Transfer; Data Center; Data Analysis & Visualization; Storing Data; Retrieving Data; Database; Send Data; Server; ICowCare Monitoring Device

Transfer
Temperature
reading every 15
minutes
Transfer the
median value of
100 accelerometer
readings every 1
second (100Hz)

Bluetooth if range <100 m
& small data
wifi if range >100 or data
contains videos

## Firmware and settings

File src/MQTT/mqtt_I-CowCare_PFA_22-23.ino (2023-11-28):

#ifdef ESP8266
#include <ESP8266WiFi.h>
#else
#include <WiFi.h>
#endif
#include <Wire.h>
#include <DFRobot_LIS2DH12.h>
#include "time.h"
#include "mqtt.h"
#include <ArduinoJson.h>
#include <PubSubClient.h>
#include <WiFiClientSecure.h>
#include <Adafruit_MLX90614.h>

/****** WiFi Connection Details *******/
const char* ssid =  "dlink_aerobotix" ; //input WiFi SSID
const char* password = "aerobotix2022" ;//input WiFi Password

int timestamp = 1;

bool online = false ; // set true if using HiveMQTT (online) and false of using Mosquitto MQTT (local broker)
// NTP server to request epoch time (required for timestamp)
const char* ntpServer = "pool.ntp.org";

/******* MQTT Broker Connection Details *******/
//condition ? expression1 : expression2;
const char* mqtt_server = "10.13.0.204"   ; //input local or online MQTT server IP address
const char* mqtt_username = "ICowCare";  // input MQTT username
const char* mqtt_password = "ICowCare1"; // input MQTT password
const int mqtt_port = 1883;              // input MQTT port

WiFiClient espClient; //if online change with WiFiClientSecure espClient;

/**** MQTT Client Initialisation Using WiFi Connection *****/
PubSubClient client(espClient);

unsigned long lastMsg = 0;
char msg[MSG_BUFFER_SIZE]; // MQTT data transfer message (buffer size : 50)

DFRobot_LIS2DH12 LIS; //Accelerometer
int16_t x, y, z;

Adafruit_MLX90614 mlx = Adafruit_MLX90614();  //Initialize temperature sensor object

/**** Application Initialisation Function******/
void setup() {
  Wire.begin();
  Serial.begin(115200);

  while (!Serial) delay(1);
  //connect to Wifi
  setup_wifi();
  configTime(0, 0, ntpServer);
  //connect to MQTT
  client.setServer(mqtt_server, mqtt_port);
  client.setCallback(callback);

  //connect to accelerometer
  while (LIS.init(LIS2DH12_RANGE_2GA) == -1) { //Equipment connection exception or I2C address error
    Serial.println("No I2C devices found");
    delay(500) ;
  }
  while (!Serial);

  //connect to temperature sensor
  if (!mlx.begin()) {
    Serial.println("Error connecting to MLX sensor. Check wiring.");
    while (1);
  };

  // enable these line and the the "certificate" code for secure connection
  /*  #ifdef ESP8266
      espClient.setInsecure();
    #else
      espClient.setCACert(root_ca);
    #endif*/

}

/******** Main Function *************/
void loop() {
  if (!client.connected()) reconnect(); // check if client is connected
  client.loop();

  //Get current timestamp
  timestamp = getTime();
  Serial.print ("time: ");
  Serial.println (timestamp);

  //Get accelerometer data
  LIS.readXYZ(x, y, z);
  LIS.mgScale(x, y, z);
  Serial.print("Acceleration x: "); //print acceleration
  Serial.print(x);
  Serial.print(" mg \ty: ");
  Serial.print(y);
  Serial.print(" mg \tz: ");
  Serial.print(z);
  Serial.println(" mg");

  //  JSON SERIALIZATION
  DynamicJsonDocument doc(128);

  //doc["deviceId"] = "Cow No 1";
  doc["accel_x"] = x;
  doc["accel_y"] = y ;
  doc["accel_z"] = z;
  //doc["timestamp"] = timestamp;

  String jsonString;
  serializeJson(doc, jsonString);

  // publish accelerometer data to topic test/accel
  publishMessage("test/accel", jsonString, true);

  // prepare different sensor data to be sent via Wifi/MQTT
  String xacc = String(x);
  String yacc = String(y);
  String zacc = String(z);
  String timestamps = String(timestamp);
  String tempAmb = String(mlx.readAmbientTempC()) ;
  String tempObj = String(mlx.readObjectTempC()) ;

  Serial.print("Ambient Temperature is");
  Serial.print(mlx.readAmbientTempC());
  Serial.println("°C");
  Serial.print("Object Temperature is");
  Serial.print(mlx.readObjectTempC());
  Serial.println("°C");

  // publish data to different topics to be used in database, dashboard ...
  publishMessage("test/cowid", "Cow No 1", true);
  publishMessage("test/x", xacc, true);
  publishMessage("test/y", yacc, true);
  publishMessage("test/z", zacc, true);
  publishMessage("test/tempamb", tempAmb, true);
  publishMessage("test/tempobj", tempObj, true);
  publishMessage("test/timestamp", timestamps, true);
  delay(100);  // delay to set data rate to 10Hz (10 data feedbacks per second) 
}

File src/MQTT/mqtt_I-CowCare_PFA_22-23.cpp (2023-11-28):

#include "mqtt.h"
#include <PubSubClient.h>

#ifdef ESP8266
#include <ESP8266WiFi.h>

#else
#include <WiFi.h>
#endif

extern const char* ssid ;
extern const char* password ;
extern const char* mqtt_server;
extern const char* mqtt_username;
extern const char* mqtt_password;
extern const int mqtt_port;
extern PubSubClient client ;
extern const char* ntpServer;

void setup_wifi() { 
  delay(10);
  Serial.print("\nConnecting to ");
  Serial.println(ssid);

  WiFi.mode(WIFI_STA);
  WiFi.begin(ssid, password);

  while (WiFi.status() != WL_CONNECTED) {
    delay(500);
    Serial.print(".");
  }
  randomSeed(micros());
  Serial.println("\nWiFi connected\nIP address: ");
  Serial.println(WiFi.localIP());
}

void reconnect() {
  // Loop until we're reconnected
  while (!client.connected()) {
    Serial.print("Attempting MQTT connection...");
    String clientId = "Vache No : ";   // Create a random client ID
    clientId += String(1);
    // Attempt to connect
   if (client.connect(clientId.c_str(), mqtt_username, mqtt_password)) {
      Serial.println("connected");

      client.subscribe("test1");   // subscribe the topics here

    } else {
      Serial.print("failed, rc=");
      Serial.print(client.state());
      Serial.println(" try again in 5 seconds");   // Wait 5 seconds before retrying
      delay(5000);
    }
  }
}

void callback(char* topic, byte* payload, unsigned int length) {
  String incommingMessage = "";
  for (int i = 0; i < length; i++) incommingMessage+=(char)payload[i];

  Serial.println("Message arrived ["+String(topic)+"]"+incommingMessage);
}
void publishMessage(const char* topic, String payload , boolean retained){
  if (client.publish(topic, payload.c_str(), true))
      Serial.println("Message publised ["+String(topic)+"]: "+payload);
}
unsigned long getTime() {
  time_t now;
  struct tm timeinfo;
  if (!getLocalTime(&timeinfo)) {
    //Serial.println("Failed to obtain time");
    return(0);
  }
  time(&now);
  return now;
}
